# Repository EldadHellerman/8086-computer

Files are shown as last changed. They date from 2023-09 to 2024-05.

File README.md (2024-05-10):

# 8086 computer

A single board 8086 based computer with a full keyboard and RGB LCD screen.
The project includes an assembler, and maybe in the future a c compiler.

It's a new version of my 8086 computer (the old one moved to repository "8086_OLD").
This one focuses mainly on PCB design.

Folders in this repository:
 - 8086 board - KiCad project folder. Schematics and PCB design.
 - assembler - Custom 8086 assembler.
 - coprocessor - Software for the coprocessor.
 - companion - Utility to communicate with the coprocessor.

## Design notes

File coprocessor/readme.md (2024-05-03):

# Coprocessor

The coprocessor is used for:
 - Generating a clock for the 8086 - The clock is required to be 33% duty cycle.
 - Generating reset signal for the 8086 - Reset is needed for a minimum clock cycles number.
 - Bridging between USB and the 8086 - It uses UART and shows as a COM port when connected to USB.
 - Reading and writing to memory - Used to upload programs, dump memory, control IO, and so on.
 - Generate interrupts - Reguler interrupts (256 different types) and NMI can be generated.
 - Test signal - Control over 8086 Test signal.
 - OPTIONAL: different peripherals:
    The coprocessor has part of the address space and can be used as different peripherals for the 8086.
    Either via direct memory r/w instructions (if AVR is fast enough), or via shared memory in RAM.
    The peripherals may be:
    - UART - using coprocessor's UART.
    - Timers - using coprocessor's timers.
    - DMA
    - FPU
    - Touch screen - ADC6 and ADC7 are available for reading,
      for driving, READY and TEST are available, and on bus hold, INTA and RCLK are available.
    - SD card - maybe common SPI lines, and use 8086 ???? as SD card CS.

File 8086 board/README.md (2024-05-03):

# 8086 board
This folder is a KiCad project folder.
It includes the 8086 PC schematics and PCB design.

## Board details

### General
- The 8086 itself.
- 128/256kB SRAM + 1024kB flash with bank select switch (only 512kB are addressable at a time, so flash is divided into two banks, meaning two complete programs can be stored at once, and selected from using the switch before boot).
- Logic for address latching (including OR gate with bus ALE).
- Expansion port allowing access to 8086 bus.
This may be used for future developments - perhapse an FPGA graphics card with HDMI output.
- LED indicators for: latched adderss, memory access (SRAM 1, SRAM 2, Flash is A19, MCU, and LCD).
- Reset button.
- USB-C port for power and communication with coprocessor.

### IO
- 320*240 or 480*320 RGB 40 pin LCD.
- 32 Push Buttons.  
They form a keyboard, with 'a'-'z', space, enter, backspace, CTRL, ALT, SHIFT.
- Logic to latch data from buttons.

### Co-Processor
- Mircocontroller used to control the 8086 (generating clock and reset signals), programming the memory and generating interrupts.
- Clock source: if I dont want to generate 33% duty cycle, than maybe a lower frequency 50% duty cycle instead.
  (make 66% of 8MHz the 50% of frequency - which is 6MHz).
- Maybe also act as peripherals (with or without interrupts): timers, UART, mouse (input from touch screen), SD card interface, etc...
- USB to UART convertor (CH340C).
- USB-C port for power and to connect to computer.
- UART connector (4p header pins or JST-XH).

## Address Space

### Segments and physical address

The 8086 uses 20-bit addressing (for 1MB total).  
The physical address is calculated from a 16-bit segment register and a 16-bit address register:

```
physical address = (segment << 4) + offset
```

For convenience, I will think of each segment as being only the 4 highest order bits (0x?000), and the memory as being comprised of 16 segments, each 64kB in size.
    
For in / out instructions, only 16-bits addressing is allowed (first segment only).

The 8086 boots to address 0xFFFF0, so there must be some memory there. That's why the flash is at the top of the memory map.  
Interrupt vector table is at 0x000 - 0x100. That's why the SRAM is at the bottom of the memory map.

<details>
<summary>Tables of memory and IO maps:</summary>

### Memory map

| Addresses | Segments  | Size  | Description |
| --- | --- | ----- | --- |
| 0x0_0000 - 0x2_0000 | 0 - 1 | 128kB | SRAM |
| 0x2_0000 - 0x4_0000 | 2 - 3 | 128kB | optional additional SRAM |
| 0x4_0000 - 0x6_0000 | 4 - 5 | 128kB | MMIO - Microcontroller |
| 0x6_0000 - 0x7_0000 | 6 | 64 kB | MMIO - RGB LCD - DATA |
| 0x7_8000 - 0x8_0000 | 7 | 64 kB | MMIO - RGB LCD  - COMMAND |
| 0x8_0000 - 0xF_FFFF | 8 - 15 | 512kB | Flash |

### IO map

IO ports are 16-bit wide.

| Number | Address | Read description | Write description |
| --- | --- | --- | --- |
| 0 | 0x0000 | 16 Push buttons. | FREE |
| 1 | 0x0002 | 16 Push buttons. | FREE |
| 2 - 7 | 0x0004 - 0x000E | FREE | FREE |

</details>

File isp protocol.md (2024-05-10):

# ISP protocol
Version 2.1  

The ISP protocol is used for communicating with the coprocessor.
This communication happens over serial, using the coprocessor UART to USB adapter.  

General structure:
- The protocol consists of packets.
- The protocol is little endian (i.e 0x1234 is sent as 0x34 and then 0x12). This matches with UART being LSB first.
- Each packet is either a command or a response. Each command is answered with a response.
- Only the computer may send commands, Only the coprocessor may send responses.
- Registers are used to control different functions, and set different settings of the coprocessor.
- Registers are identified by a 1-byte number, and are 4-bytes wide (although using only parts of the bits is possible).

Packets have the following fields (at that order):
| field name | size (bytes)  |
| --- | --- |
| preamble | 2 |
| packet id | 1 |
| data length | 2 |
| data | 0 - 65,535 |

For preamble, the value 0xAA55 is used.

## Packets:
| packet id | name | type | description | data length | data (length in bytes) |
| --- | --- | --- | --- | --- | --- |
| 0x00 | READ_REG | command  | read from a register | 1 | register number (1) |
| 0x01 | WRITE_REG | command  | write to a register | 5 | register number (1), value (4) |
| 0x02 | READ_BUS | command  | read from the bus | 6 | address (4), length (2) |
| 0x03 | WRITE_BUS | command  | write to the bus | variable | address (4), data (variable) |
| 0x04 | WRITE_FLASH | command  | write to / program flash | variable | address (4), data (variable) |
| 0x10 | SUCCESS | response | successful operation | 0 | none |
| | | | successful READ_REGISTER | 4 | value of register (4) |
| | | | successful READ_BUS | variable | data (variable) |
| 0x11 | FAILURE | response | failure | 0 | none |

## Registers:
| number | name | value on read | value on read description | value on write | value on write description |
| --- | --- | --- | --- | --- | --- |
| 0x00 | STATUS | status | status. indicates error types TODO | status | |
| 0x01 | DEVICE_ID | 0xXXXXXXXX | unique device id | | |
| 0x02 | FIRMWARE_VERSION | 0xXXXXXXXX | firmware version | | |
| 0x03 | PROTOCOL_VERSION | 0xXXXXXXXX | protocol version | | |
| 0x04 | CLOCK_SPEED | TODO | generated clock speed | TODO | same |
| 0x05 | UART_SPEED | TODO | communication uart speed | TODO | same |
| 0x06 | RESET_TIME | TODO | TODO | TODO | same |
| 0x07 | TIMEOUT | TODO | TODO | TODO | same |
| 0x08 | GPIO_TEST | 0 - 1 | input level of test pin | 0 - 1 | output level of test pin |
| 0x10 | RESET | | | 1 | Resets the 8086 |
| | | | | 2 | Resets 8086 and holds bus |
| 0x11 | BUS_HOLD | 0 - 1 | Bus on hold indicator | 0 - 1 | Release or hold bus |
| 0x12 | INTERRUPT | | | 0 - 255 | Generates corresponding interrupts |
| | | | | 256 | Generates NMI |

### Status register:
| bit index | description |
| --- | --- |
| 0 | INVALID_PACKET_ID |
| 1 | INVALID_REGISTER |
| 2 | INVALID_DATA_LENGTH |

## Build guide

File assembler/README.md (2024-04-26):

# Assembler

## Assembly syntax and directives

Comments:
```
// this is a one line comment
/* this is
a multiline comment */
```

labels:  
```
/*
All labels start with '$'.
'$' is the location at the start of current line.
*/

$jump: //defining label
    mov ax, $jump //using label
    mov ax, [$jump] //using label
    jmp $continue + 1 // label math, skip NOP
$continue:
    NOP
    JMP $ // infinite loop
```

Line endings:
```
/*
';' is used to seperate commands on the same line.
'\n' or '\r\n' are used to move to next line.
*/
mov ax, 5; mov bx, 6  ;mov cx,7  // Valid. 3 commands in one line.
```

Assembler directives:
All assembler directives start with a dot.
```
.incbin "file.bin"
.section .text
.extern main
```

Constants:
```
// constants prefixes are case insensitive

// integers (underscore seperators are allowed):
.db -24, +35_000                // decimal
.db 0x12_34                     // hex
.db 0o45                        // octal
.db 0b0110_0011                 // binary
.db 'a'                         // ascii
.dd 2.0, -2f, 1.23, +4.35e-2    // float

// String constants:
"str" // This is considered the same as 's', 't', 'r', '\0'.
```

General:
```
mov DST, SRC // DST is on the left, SRC is on the right.

mov byte [0x3456], 0x20
mov AL, byte [0x3456]
mov AL, [0x3456] // Implicit byte. Optional warning.

mov [0x3456], 0x20 // Unknowen size. Error.
inc [0x3456] // Unknowen size. Error.

mov ax, [ES : 0x04] // Segment override is inside the square brackets.
```

## Preprocessor Directives

```
#include "file"
#ifndef GUARD
#define GUARD
#endif

#define const 5

#define macro1(x)   mov ax, 5
#define macro2(a,b) (bp + si + a*8 + b)

#macro macro3
    mov ax, 0
    ret
#endmacro

#if 4 < 5
mov ax, 5
#endif
```

Comments:
```
// this is a one line comment
/* this is
a multiline comment */
```

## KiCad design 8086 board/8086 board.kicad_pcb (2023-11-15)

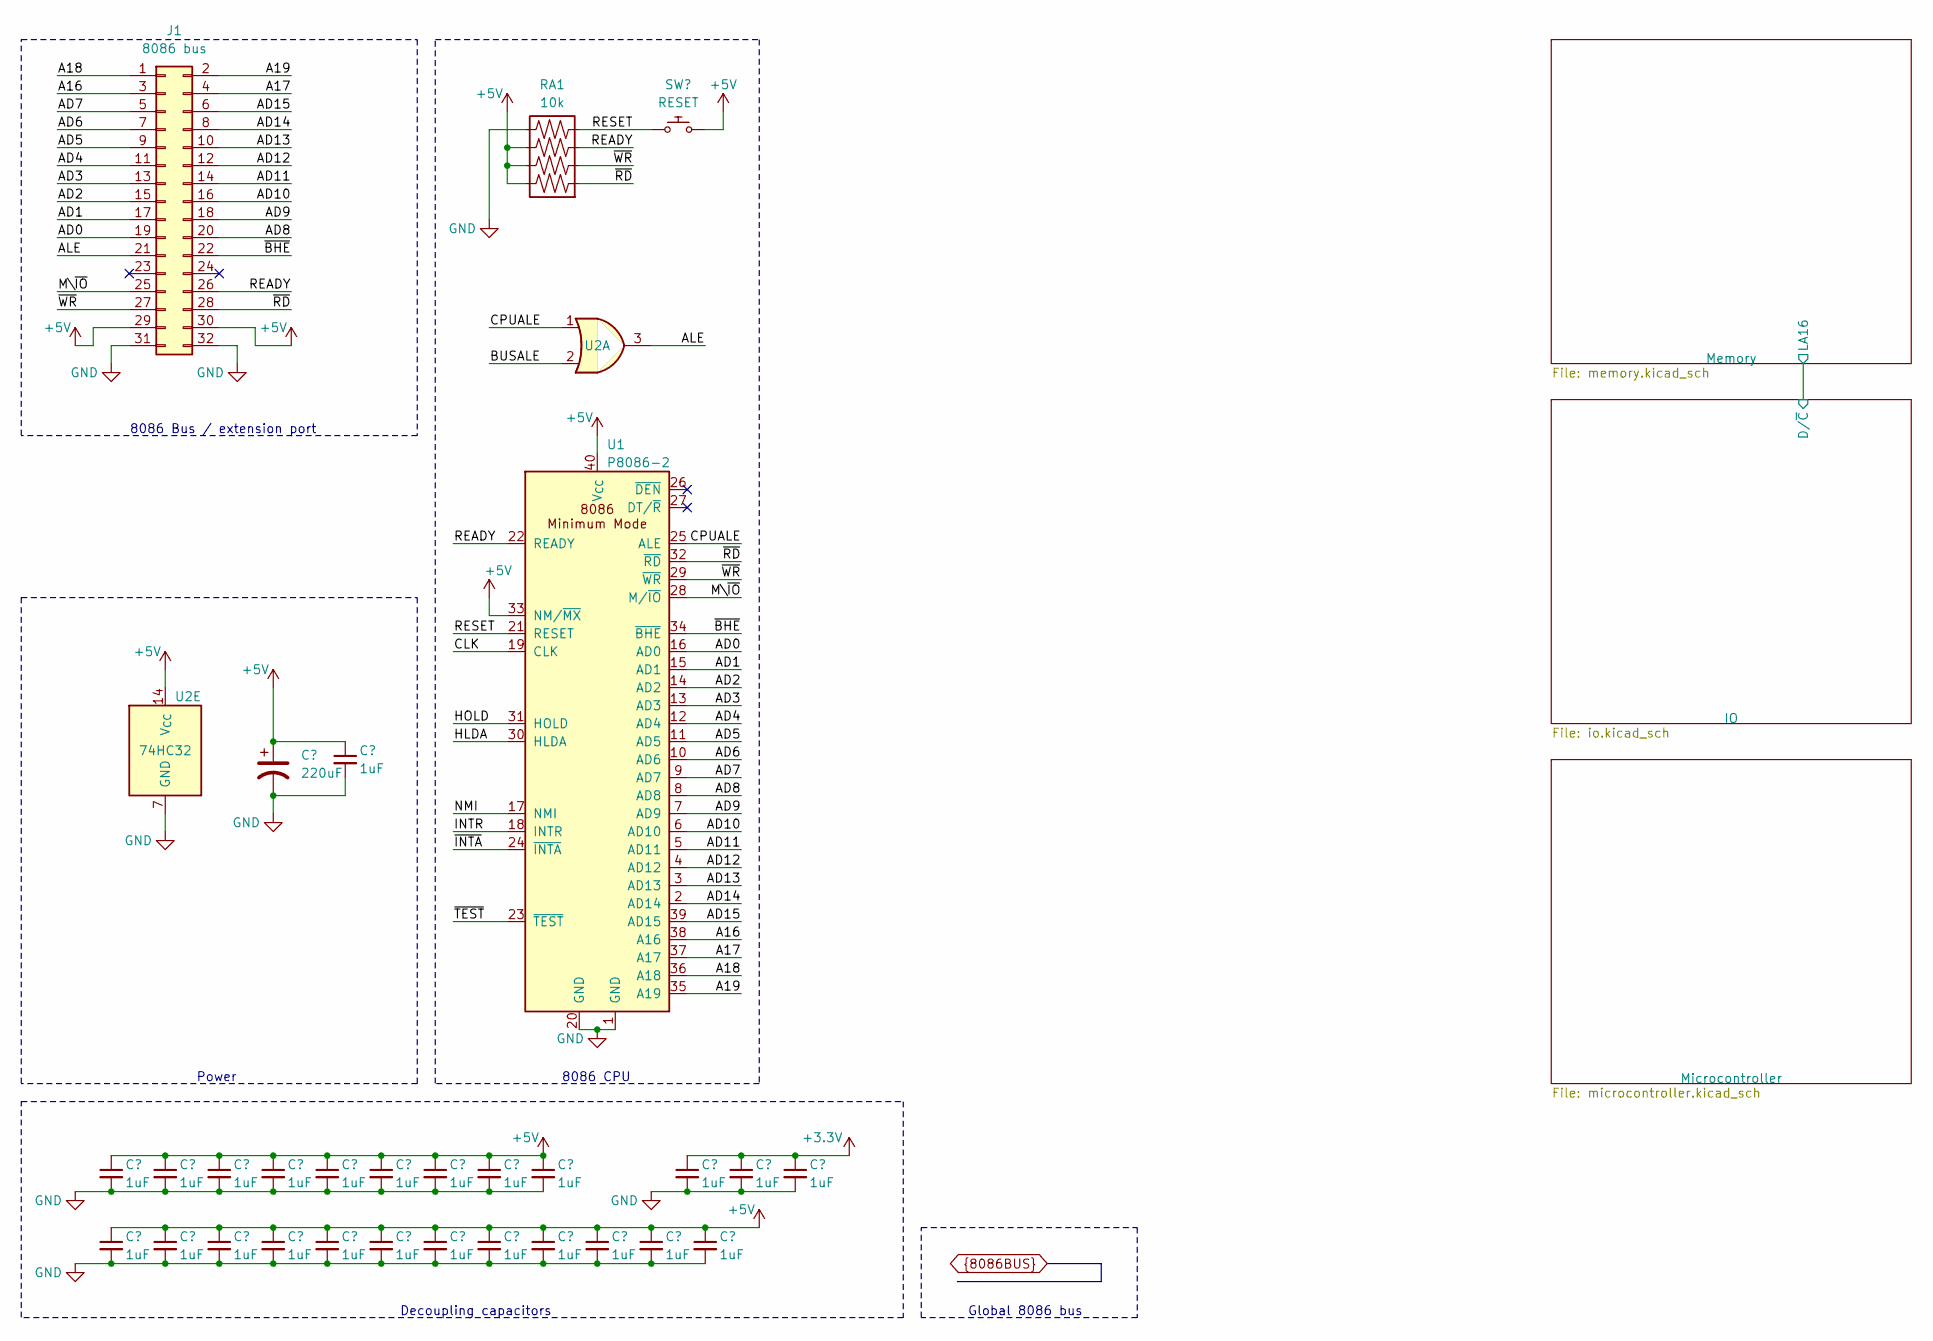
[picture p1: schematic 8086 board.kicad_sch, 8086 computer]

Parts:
C3: 220uF; CP_EIA-7343-43_Kemet-X_Pad2.25x2.55mm_HandSolder
C8, C9, C10, C11, C12, C13, C14, C15, C16, C17, C18, C19, C20, C21, C22, C23, C24, C25, C26, C27, C28, C29, C30, C31, C32: 1uF; C_0603_1608Metric_Pad1.08x0.95mm_HandSolder
J1: 8086 bus; PinHeader_2x16_P2.54mm_Vertical
RA1: 10k; R_Array_Concave_4x0603
SW33: RESET; SW_Push_6x6x5mm
U1: P8086-2; DIP-40_W15.24mm
U2: 74HC32; TSSOP-14_4.4x5mm_P0.65mm

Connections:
+3.3V: C17.1, C18.1, C19.1; also elsewhere on the board
+5V: C3.1, C8.1, C9.1, C10.1, C11.1, C12.1, C13.1, C14.1, C15.1, C16.1, C20.1, C21.1, C22.1, C23.1, C24.1, C25.1, C26.1, C27.1, C28.1, C29.1, C30.1, C31.1, C32.1, J1.29, J1.30, RA1.6, RA1.7, RA1.8, SW33.1, U1.33 (NM/~MX), U1.40 (V_{CC}), U2.14 (V_{CC}); also elsewhere on the board
/CPUALE: U1.25 (ALE), U2.1
A16: J1.3, U1.38 (A16); also elsewhere on the board
A17: J1.4, U1.37 (A17); also elsewhere on the board
A18: J1.1, U1.36 (A18); also elsewhere on the board
A19: J1.2, U1.35 (A19); also elsewhere on the board
AD0: J1.19, U1.16 (AD0); also elsewhere on the board
AD1: J1.17, U1.15 (AD1); also elsewhere on the board
AD2: J1.15, U1.14 (AD2); also elsewhere on the board
AD3: J1.13, U1.13 (AD3); also elsewhere on the board
AD4: J1.11, U1.12 (AD4); also elsewhere on the board
AD5: J1.9, U1.11 (AD5); also elsewhere on the board
AD6: J1.7, U1.10 (AD6); also elsewhere on the board
AD7: J1.5, U1.9 (AD7); also elsewhere on the board
AD8: J1.20, U1.8 (AD8); also elsewhere on the board
AD9: J1.18, U1.7 (AD9); also elsewhere on the board
AD10: J1.16, U1.6 (AD10); also elsewhere on the board
AD11: J1.14, U1.5 (AD11); also elsewhere on the board
AD12: J1.12, U1.4 (AD12); also elsewhere on the board
AD13: J1.10, U1.3 (AD13); also elsewhere on the board
AD14: J1.8, U1.2 (AD14); also elsewhere on the board
AD15: J1.6, U1.39 (AD15); also elsewhere on the board
ALE: J1.21, U2.3; also elsewhere on the board
BUSALE: U2.2; also elsewhere on the board
CLK: U1.19 (CLK); also elsewhere on the board
GND: C3.2, C8.2, C9.2, C10.2, C11.2, C12.2, C13.2, C14.2, C15.2, C16.2, C17.2, C18.2, C19.2, C20.2, C21.2, C22.2, C23.2, C24.2, C25.2, C26.2, C27.2, C28.2, C29.2, C30.2, C31.2, C32.2, J1.31, J1.32, RA1.5, U1.1 (GND), U1.20 (GND), U2.7 (GND); also elsewhere on the board
HLDA: U1.30 (HLDA); also elsewhere on the board
HOLD: U1.31 (HOLD); also elsewhere on the board
INTR: U1.18 (INTR); also elsewhere on the board
M\~IO: J1.25, U1.28 (M/~IO); also elsewhere on the board
NMI: U1.17 (NMI); also elsewhere on the board
READY: J1.26, RA1.3, U1.22 (READY); also elsewhere on the board
RESET: RA1.4, SW33.2, U1.21 (RESET); also elsewhere on the board
~BHE: J1.22, U1.34 (~BHE); also elsewhere on the board
~INTA: U1.24 (~INTA); also elsewhere on the board
~RD: J1.28, RA1.1, U1.32 (~RD); also elsewhere on the board
~TEST: U1.23 (~TEST); also elsewhere on the board
~WR: J1.27, RA1.2, U1.29 (~WR); also elsewhere on the board

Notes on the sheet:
Power
8086 Bus / extension port
Decoupling capacitors
Global 8086 bus
8086 CPU

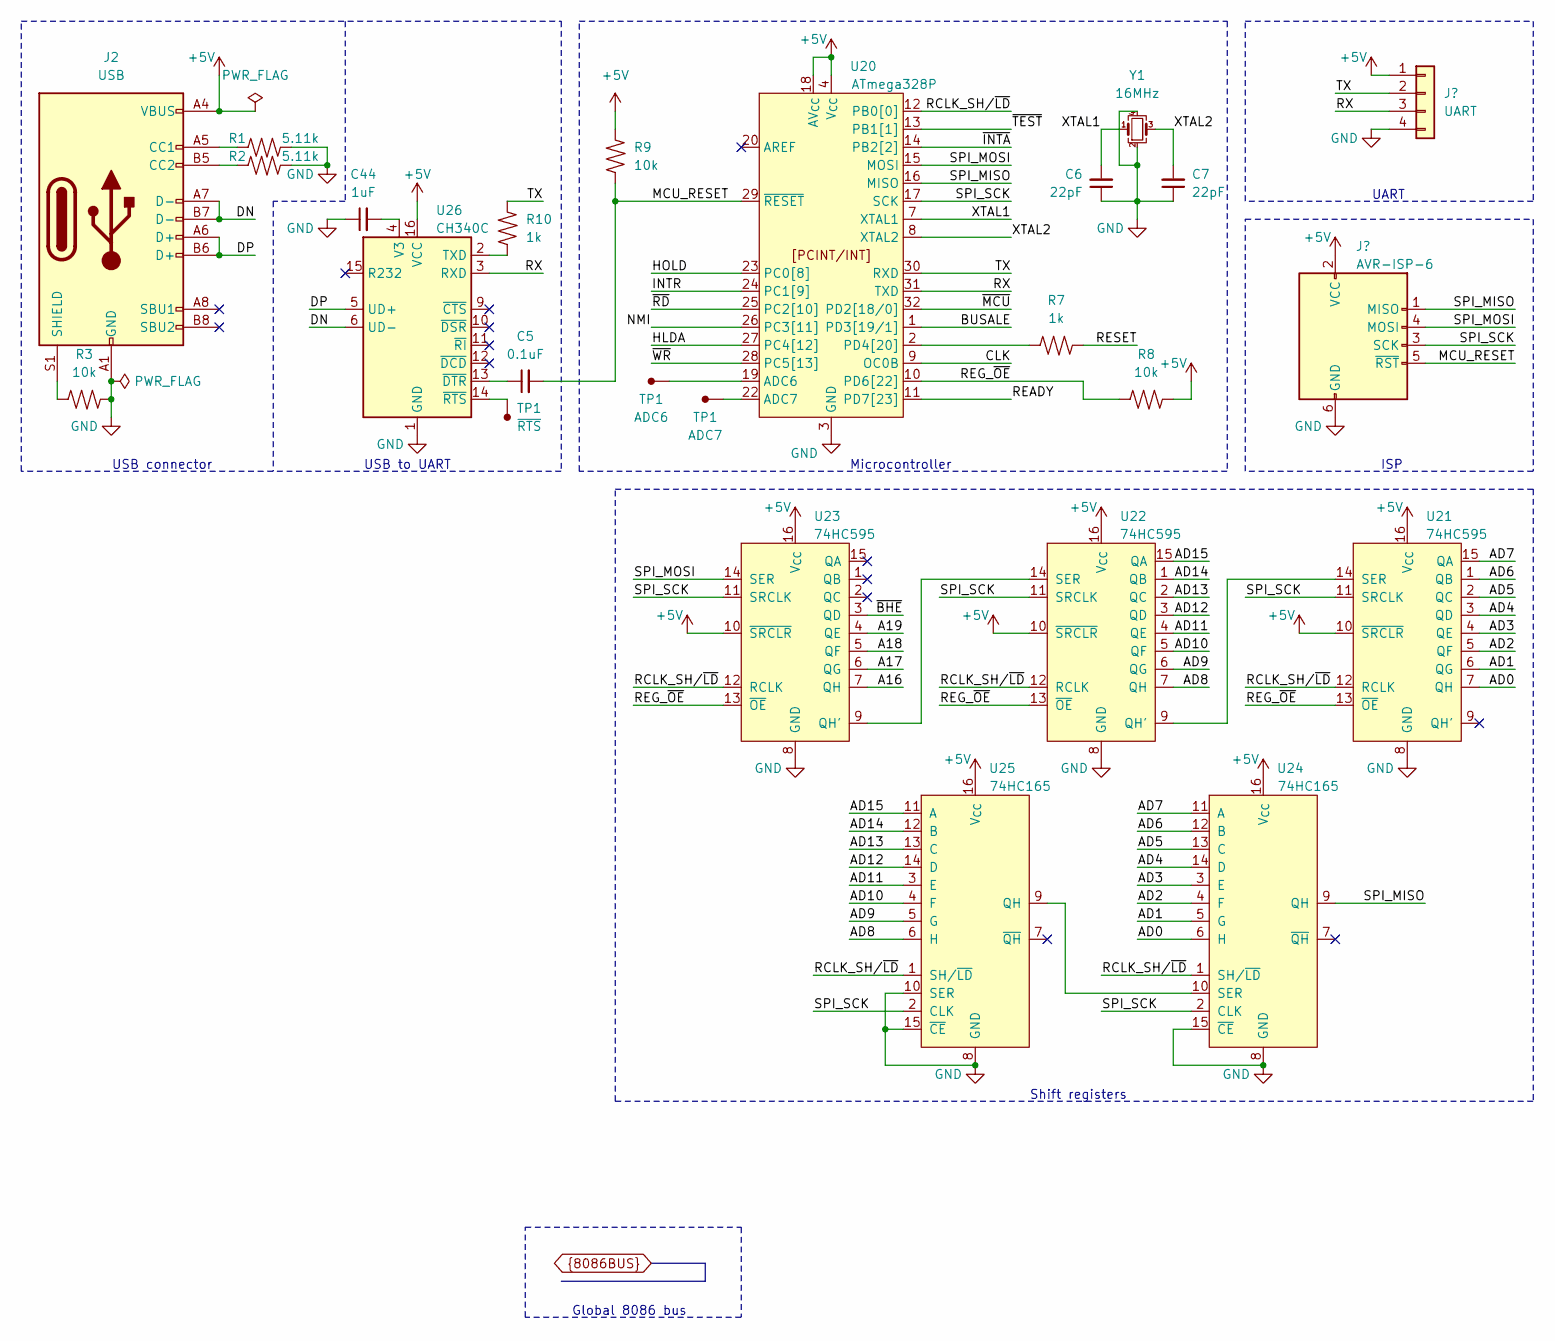
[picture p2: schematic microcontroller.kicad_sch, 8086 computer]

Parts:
C5: 0.1uF; C_0603_1608Metric_Pad1.08x0.95mm_HandSolder
C6, C7: 22pF; C_0603_1608Metric_Pad1.08x0.95mm_HandSolder
C44: 1uF; C_0603_1608Metric_Pad1.08x0.95mm_HandSolder
J2: USB; USB_C_Receptacle_GCT_USB4105-xx-A_16P_TopMnt_Horizontal
J4: UART; PinHeader_1x04_P2.54mm_Vertical
J5: AVR-ISP-6; PinHeader_2x03_P2.54mm_Vertical
R1, R2: 5.11k; R_0603_1608Metric_Pad0.98x0.95mm_HandSolder
R3, R8, R9: 10k; R_0603_1608Metric_Pad0.98x0.95mm_HandSolder
R7, R10: 1k; R_0603_1608Metric_Pad0.98x0.95mm_HandSolder
TP1: ADC6; TestPoint_Pad_1.5x1.5mm
U20: ATmega328P; TQFP-32_7x7mm_P0.8mm
U21, U22, U23: 74HC595; TSSOP-16_4.4x5mm_P0.65mm
U24, U25: 74HC165; TSSOP-16_4.4x5mm_P0.65mm
U26: CH340C; SOIC-16_3.9x9.9mm_P1.27mm
Y1: 16MHz; Crystal_SMD_3225-4Pin_3.2x2.5mm_HandSoldering

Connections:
+5V: J2.A4 (VBUS), J2.A9 (VBUS), J2.B4 (VBUS), J2.B9 (VBUS), J4.1, J5.2 (VCC), R8.2, R9.2, U20.4 (V_{CC}), U20.6 (V_{CC}), U20.18 (AV_{CC}), U21.10 (~SRCLR), U21.16 (V_{CC}), U22.10 (~SRCLR), U22.16 (V_{CC}), U23.10 (~SRCLR), U23.16 (V_{CC}), U24.16 (V_{CC}), U25.16 (V_{CC}); also elsewhere on the board
/Microcontroller/DN: J2.A7 (D-), J2.B7 (D-); also elsewhere on the board
/Microcontroller/DP: J2.A6 (D+), J2.B6 (D+); also elsewhere on the board
/Microcontroller/MCU_RESET: C5.2, J5.5 (~RST), R9.1, U20.29 (~RESET)
/Microcontroller/RCLK_SH/~LD: U20.12 (PB0[0]), U21.12 (RCLK), U22.12 (RCLK), U23.12 (RCLK), U24.1 (SH/~LD), U25.1 (SH/~LD)
/Microcontroller/REG_~OE: R8.1, U20.10 (PD6[22]), U21.13 (~OE), U22.13 (~OE), U23.13 (~OE)
/Microcontroller/RX: J4.3, U20.31 (TXD); also elsewhere on the board
/Microcontroller/SPI_MISO: J5.1 (MISO), U20.16 (MISO), U24.9 (QH)
/Microcontroller/SPI_MOSI: J5.4 (MOSI), U20.15 (MOSI), U23.14 (SER)
/Microcontroller/SPI_SCK: J5.3 (SCK), U20.17 (SCK), U21.11 (SRCLK), U22.11 (SRCLK), U23.11 (SRCLK), U24.2 (CLK), U25.2 (CLK)
/Microcontroller/TX: J4.2, R10.2, U20.30 (RXD)
/Microcontroller/XTAL1: C6.2, U20.7 (XTAL1), Y1.1
/Microcontroller/XTAL2: C7.2, U20.8 (XTAL2), Y1.3
A16: U23.7 (QH); also elsewhere on the board
A17: U23.6 (QG); also elsewhere on the board
A18: U23.5 (QF); also elsewhere on the board
A19: U23.4 (QE); also elsewhere on the board
AD0: U21.7 (QH), U24.6 (H); also elsewhere on the board
AD1: U21.6 (QG), U24.5 (G); also elsewhere on the board
AD2: U21.5 (QF), U24.4 (F); also elsewhere on the board
AD3: U21.4 (QE), U24.3 (E); also elsewhere on the board
AD4: U21.3 (QD), U24.14 (D); also elsewhere on the board
AD5: U21.2 (QC), U24.13 (C); also elsewhere on the board
AD6: U21.1 (QB), U24.12 (B); also elsewhere on the board
AD7: U21.15 (QA), U24.11 (A); also elsewhere on the board
AD8: U22.7 (QH), U25.6 (H); also elsewhere on the board
AD9: U22.6 (QG), U25.5 (G); also elsewhere on the board
AD10: U22.5 (QF), U25.4 (F); also elsewhere on the board
AD11: U22.4 (QE), U25.3 (E); also elsewhere on the board
AD12: U22.3 (QD), U25.14 (D); also elsewhere on the board
AD13: U22.2 (QC), U25.13 (C); also elsewhere on the board
AD14: U22.1 (QB), U25.12 (B); also elsewhere on the board
AD15: U22.15 (QA), U25.11 (A); also elsewhere on the board
BUSALE: U20.1 (PD3[19/1]); also elsewhere on the board
CLK: U20.9 (OC0B); also elsewhere on the board
GND: C6.1, C7.1, J2.A1 (GND), J2.A12 (GND), J2.B1 (GND), J2.B12 (GND), J4.4, J5.6 (GND), R1.2, R2.2, R3.2, U20.3 (GND), U20.5 (GND), U20.21 (GND), U21.8 (GND), U22.8 (GND), U23.8 (GND), U24.8 (GND), U24.15 (~CE), U25.8 (GND), U25.10 (SER), U25.15 (~CE), Y1.2, Y1.4; also elsewhere on the board
HLDA: U20.27 (PC4[12]); also elsewhere on the board
HOLD: U20.23 (PC0[8]); also elsewhere on the board
INTR: U20.24 (PC1[9]); also elsewhere on the board
NMI: U20.26 (PC3[11]); also elsewhere on the board
unnamed: J2.A5 (CC1), R1.1
unnamed: J2.B5 (CC2), R2.1
unnamed: J2.S1 (SHIELD), R3.1
unnamed 155: R10.1; also elsewhere on the board
unnamed 157: C5.1; also elsewhere on the board
unnamed: R7.1, U20.2 (PD4[20])
unnamed: U21.14 (SER), U22.9 (QH')
unnamed: U22.14 (SER), U23.9 (QH')
unnamed: U24.10 (SER), U25.9 (QH)
READY: U20.11 (PD7[23]); also elsewhere on the board
RESET: R7.2; also elsewhere on the board
~BHE: U23.3 (QD); also elsewhere on the board
~INTA: U20.14 (PB2[2]); also elsewhere on the board
~MCU: U20.32 (PD2[18/0]); also elsewhere on the board
~RD: U20.25 (PC2[10]); also elsewhere on the board
~TEST: U20.13 (PB1[1]); also elsewhere on the board
~WR: U20.28 (PC5[13]); also elsewhere on the board

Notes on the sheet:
UART
ISP
Microcontroller
USB to UART
USB connector
Global 8086 bus
Shift registers

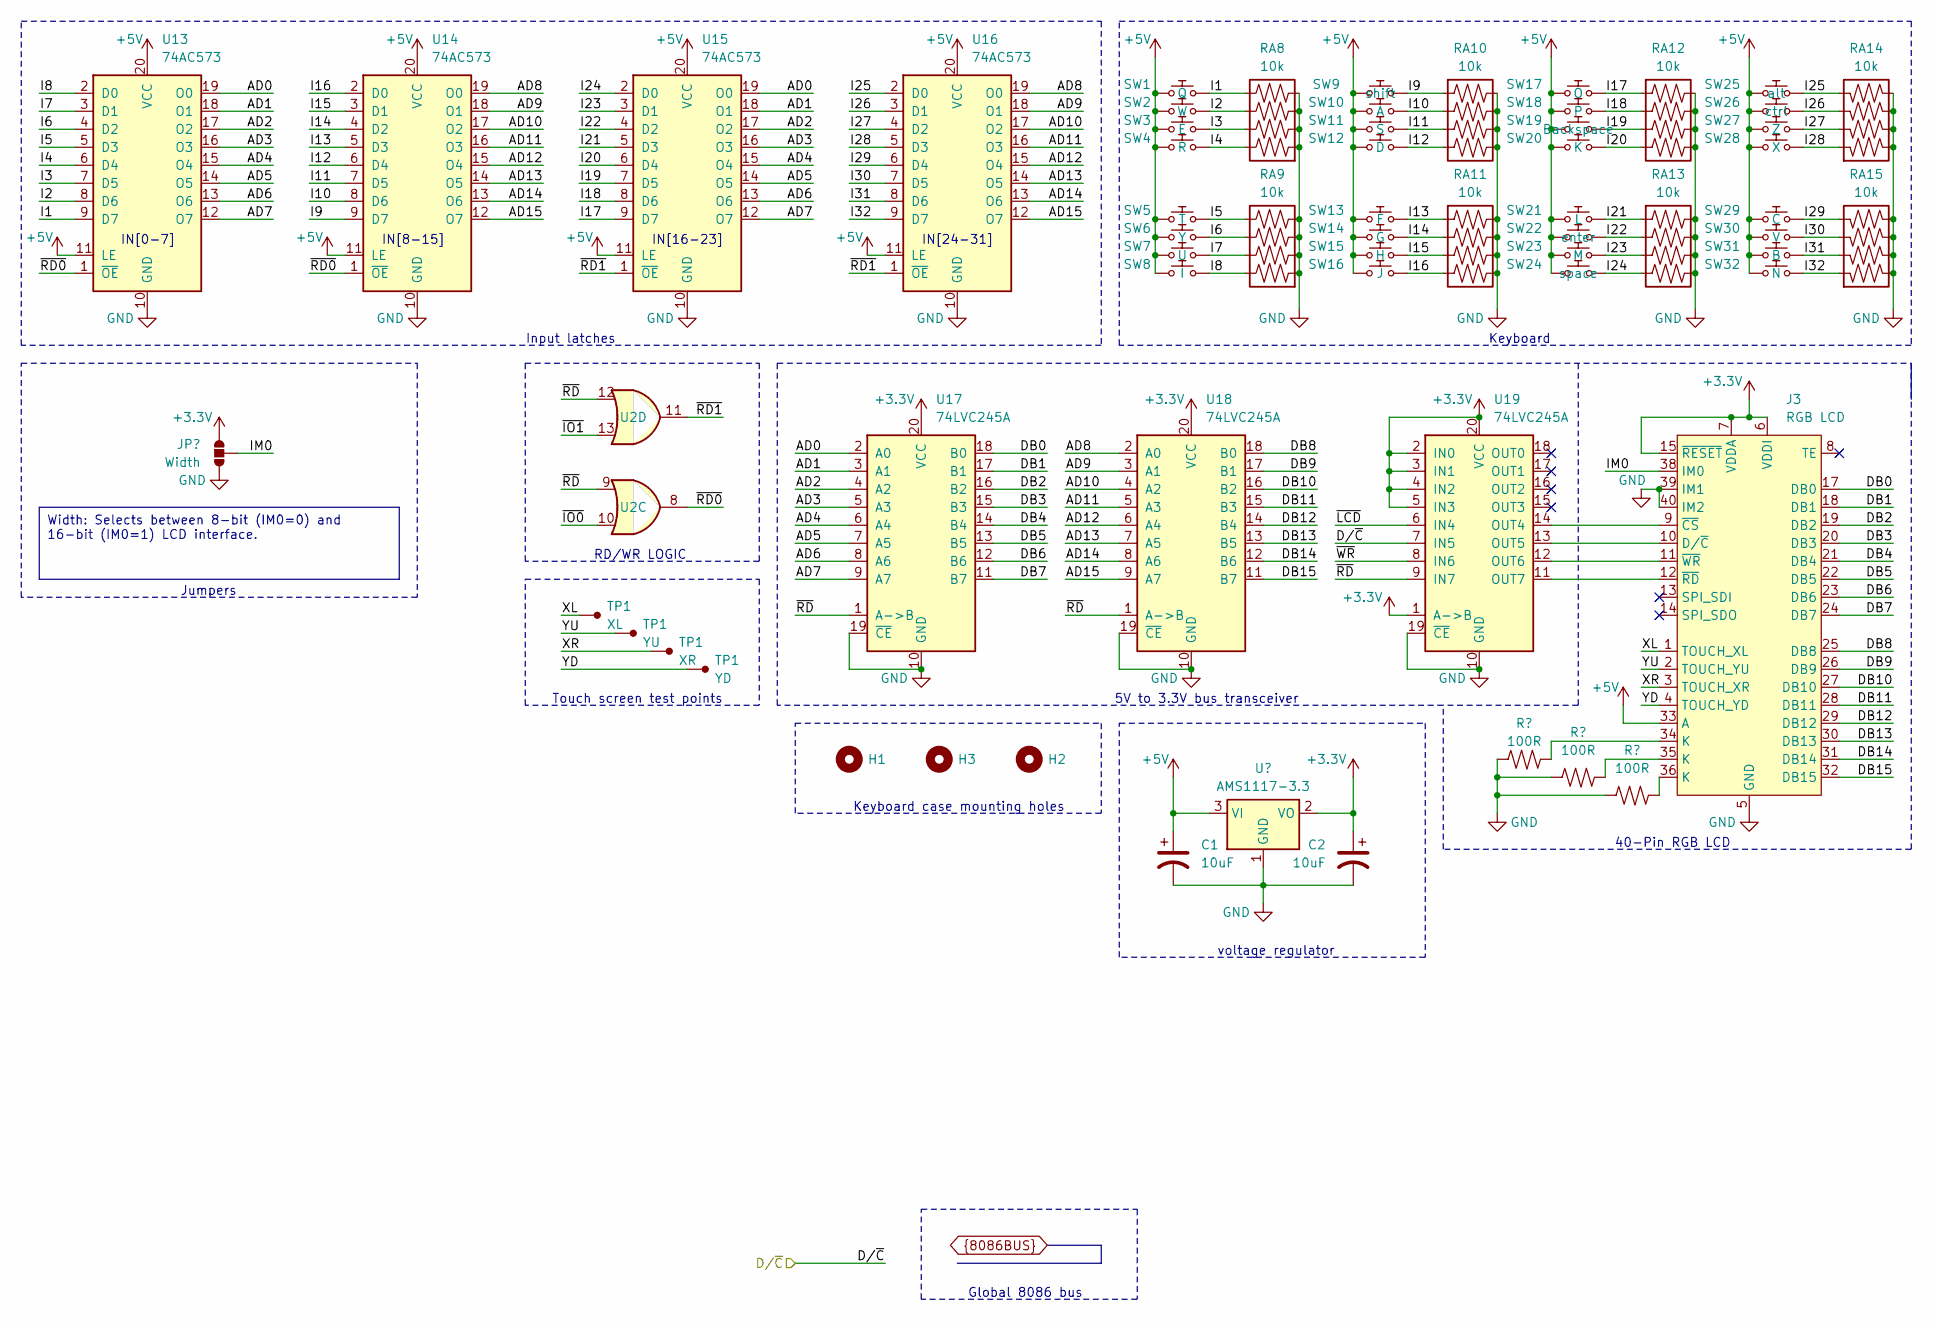
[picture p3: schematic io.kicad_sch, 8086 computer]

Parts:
C1, C2: 10uF; C_0603_1608Metric_Pad1.08x0.95mm_HandSolder
H1, H2, H3: MountingHole_3.2mm_M3_DIN965
J3: RGB LCD; FPC_40
JP1: Width; SolderJumper-3_P1.3mm_Bridged12_RoundedPad1.0x1.5mm
R4, R5, R6: 100R; R_0603_1608Metric_Pad0.98x0.95mm_HandSolder
RA8, RA9, RA10, RA11, RA12, RA13, RA14, RA15: 10k; R_Array_Concave_4x0603
SW1: Q; SW_Push_6x6x5mm
SW2: W; SW_Push_6x6x5mm
SW3: E; SW_Push_6x6x5mm
SW4: R; SW_Push_6x6x5mm
SW5: T; SW_Push_6x6x5mm
SW6: Y; SW_Push_6x6x5mm
SW7: U; SW_Push_6x6x5mm
SW8: I; SW_Push_6x6x5mm
SW9: shift; SW_Push_6x6x5mm
SW10: A; SW_Push_6x6x5mm
SW11: S; SW_Push_6x6x5mm
SW12: D; SW_Push_6x6x5mm
SW13: F; SW_Push_6x6x5mm
SW14: G; SW_Push_6x6x5mm
SW15: H; SW_Push_6x6x5mm
SW16: J; SW_Push_6x6x5mm
SW17: O; SW_Push_6x6x5mm
SW18: P; SW_Push_6x6x5mm
SW19: Backspace; SW_Push_6x6x5mm
SW20: K; SW_Push_6x6x5mm
SW21: L; SW_Push_6x6x5mm
SW22: enter; SW_Push_6x6x5mm
SW23: M; SW_Push_6x6x5mm
SW24: space; SW_Push_6x6x5mm
SW25: alt; SW_Push_6x6x5mm
SW26: ctrl; SW_Push_6x6x5mm
SW27: Z; SW_Push_6x6x5mm
SW28: X; SW_Push_6x6x5mm
SW29: C; SW_Push_6x6x5mm
SW30: V; SW_Push_6x6x5mm
SW31: B; SW_Push_6x6x5mm
SW32: N; SW_Push_6x6x5mm
TP1: XR; TestPoint_Pad_1.5x1.5mm
U2: 74HC32; TSSOP-14_4.4x5mm_P0.65mm
U3: AMS1117-3.3; SOT-223-3_TabPin2
U13, U14, U15, U16: 74AC573; TSSOP-20_4.4x6.5mm_P0.65mm
U17, U18, U19: 74LVC245A; TSSOP-20_4.4x6.5mm_P0.65mm

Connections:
+3.3V: C2.1, J3.6 (VDDI), J3.7 (VDDA), J3.15 (~RESET), JP1.1, U3.2 (VO), U17.20 (VCC), U18.20 (VCC), U19.1 (A->B), U19.2 (IN0), U19.3 (IN1), U19.4 (IN2), U19.5 (IN3), U19.20 (VCC); also elsewhere on the board
+5V: C1.1, J3.33 (A), SW1.1, SW2.2, SW3.1, SW4.2, SW5.1, SW6.2, SW7.1, SW8.2, SW9.1, SW10.2, SW11.1, SW12.2, SW13.1, SW14.2, SW15.1, SW16.2, SW17.1, SW18.2, SW19.1, SW20.1, SW21.2, SW22.1, SW23.1, SW24.1, SW25.1, SW26.2, SW27.1, SW28.2, SW29.1, SW30.2, SW31.1, SW32.2, U3.3 (VI), U13.11 (LE), U13.20 (VCC), U14.11 (LE), U14.20 (VCC), U15.11 (LE), U15.20 (VCC), U16.11 (LE), U16.20 (VCC); also elsewhere on the board
/IO/DB0: J3.17 (DB0), U17.18 (B0)
/IO/DB1: J3.18 (DB1), U17.17 (B1)
/IO/DB2: J3.19 (DB2), U17.16 (B2)
/IO/DB3: J3.20 (DB3), U17.15 (B3)
/IO/DB4: J3.21 (DB4), U17.14 (B4)
/IO/DB5: J3.22 (DB5), U17.13 (B5)
/IO/DB6: J3.23 (DB6), U17.12 (B6)
/IO/DB7: J3.24 (DB7), U17.11 (B7)
/IO/DB8: J3.25 (DB8), U18.18 (B0)
/IO/DB9: J3.26 (DB9), U18.17 (B1)
/IO/DB10: J3.27 (DB10), U18.16 (B2)
/IO/DB11: J3.28 (DB11), U18.15 (B3)
/IO/DB12: J3.29 (DB12), U18.14 (B4)
/IO/DB13: J3.30 (DB13), U18.13 (B5)
/IO/DB14: J3.31 (DB14), U18.12 (B6)
/IO/DB15: J3.32 (DB15), U18.11 (B7)
/IO/D/~C: U19.7 (IN5); also elsewhere on the board
/IO/I1: RA8.5, SW1.2, U13.9 (D7)
/IO/I2: RA8.6, SW2.1, U13.8 (D6)
/IO/I3: RA8.7, SW3.2, U13.7 (D5)
/IO/I4: RA8.8, SW4.1, U13.6 (D4)
/IO/I5: RA9.5, SW5.2, U13.5 (D3)
/IO/I6: RA9.6, SW6.1, U13.4 (D2)
/IO/I7: RA9.7, SW7.2, U13.3 (D1)
/IO/I8: RA9.8, SW8.1, U13.2 (D0)
/IO/I9: RA10.1, SW9.2, U14.9 (D7)
/IO/I10: RA10.2, SW10.1, U14.8 (D6)
/IO/I11: RA10.3, SW11.2, U14.7 (D5)
/IO/I12: RA10.4, SW12.1, U14.6 (D4)
/IO/I13: RA11.1, SW13.2, U14.5 (D3)
/IO/I14: RA11.2, SW14.1, U14.4 (D2)
/IO/I15: RA11.3, SW15.2, U14.3 (D1)
/IO/I16: RA11.4, SW16.1, U14.2 (D0)
/IO/I17: RA12.1, SW17.2, U15.9 (D7)
/IO/I18: RA12.2, SW18.1, U15.8 (D6)
/IO/I19: RA12.3, SW19.2, U15.7 (D5)
/IO/I20: RA12.4, SW20.2, U15.6 (D4)
/IO/I21: RA13.1, SW21.1, U15.5 (D3)
/IO/I22: RA13.2, SW22.2, U15.4 (D2)
/IO/I23: RA13.3, SW23.2, U15.3 (D1)
/IO/I24: RA13.4, SW24.2, U15.2 (D0)
/IO/I25: RA14.4, SW25.2, U16.2 (D0)
/IO/I26: RA14.3, SW26.1, U16.3 (D1)
/IO/I27: RA14.2, SW27.2, U16.4 (D2)
/IO/I28: RA14.1, SW28.1, U16.5 (D3)
/IO/I29: RA15.4, SW29.2, U16.6 (D4)
/IO/I30: RA15.3, SW30.1, U16.7 (D5)
/IO/I31: RA15.2, SW31.2, U16.8 (D6)
/IO/I32: RA15.1, SW32.1, U16.9 (D7)
/IO/IM0: J3.38 (IM0), JP1.2
/IO/~RD0: U2.8, U13.1 (~OE), U14.1 (~OE)
/IO/~RD1: U2.11, U15.1 (~OE), U16.1 (~OE)
AD0: U13.19 (O0), U15.19 (O0), U17.2 (A0); also elsewhere on the board
AD1: U13.18 (O1), U15.18 (O1), U17.3 (A1); also elsewhere on the board
AD2: U13.17 (O2), U15.17 (O2), U17.4 (A2); also elsewhere on the board
AD3: U13.16 (O3), U15.16 (O3), U17.5 (A3); also elsewhere on the board
AD4: U13.15 (O4), U15.15 (O4), U17.6 (A4); also elsewhere on the board
AD5: U13.14 (O5), U15.14 (O5), U17.7 (A5); also elsewhere on the board
AD6: U13.13 (O6), U15.13 (O6), U17.8 (A6); also elsewhere on the board
AD7: U13.12 (O7), U15.12 (O7), U17.9 (A7); also elsewhere on the board
AD8: U14.19 (O0), U16.19 (O0), U18.2 (A0); also elsewhere on the board
AD9: U14.18 (O1), U16.18 (O1), U18.3 (A1); also elsewhere on the board
AD10: U14.17 (O2), U16.17 (O2), U18.4 (A2); also elsewhere on the board
AD11: U14.16 (O3), U16.16 (O3), U18.5 (A3); also elsewhere on the board
AD12: U14.15 (O4), U16.15 (O4), U18.6 (A4); also elsewhere on the board
AD13: U14.14 (O5), U16.14 (O5), U18.7 (A5); also elsewhere on the board
AD14: U14.13 (O6), U16.13 (O6), U18.8 (A6); also elsewhere on the board
AD15: U14.12 (O7), U16.12 (O7), U18.9 (A7); also elsewhere on the board
GND: C1.2, C2.2, J3.5 (GND), J3.16 (GND), J3.37 (GND), J3.39 (IM1), J3.40 (IM2), JP1.3, R4.1, R5.1, R6.1, RA8.1, RA8.2, RA8.3, RA8.4, RA9.1, RA9.2, RA9.3, RA9.4, RA10.5, RA10.6, RA10.7, RA10.8, RA11.5, RA11.6, RA11.7, RA11.8, RA12.5, RA12.6, RA12.7, RA12.8, RA13.5, RA13.6, RA13.7, RA13.8, RA14.5, RA14.6, RA14.7, RA14.8, RA15.5, RA15.6, RA15.7, RA15.8, U3.1 (GND), U13.10 (GND), U14.10 (GND), U15.10 (GND), U16.10 (GND), U17.10 (GND), U17.19 (~CE), U18.10 (GND), U18.19 (~CE), U19.10 (GND), U19.19 (~CE); also elsewhere on the board
unnamed: J3.10 (D/~C), U19.13 (OUT5)
unnamed: J3.34 (K), R4.2
unnamed: J3.35 (K), R5.2
unnamed: J3.36 (K), R6.2
unnamed: J3.9 (~CS), U19.14 (OUT4)
unnamed: J3.12 (~RD), U19.11 (OUT7)
unnamed: J3.11 (~WR), U19.12 (OUT6)
~IO0: U2.10; also elsewhere on the board
~IO1: U2.13; also elsewhere on the board
~LCD: U19.6 (IN4); also elsewhere on the board
~RD: U2.9, U2.12, U17.1 (A->B), U18.1 (A->B), U19.9 (IN7); also elsewhere on the board
~WR: U19.8 (IN6); also elsewhere on the board

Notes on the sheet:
Width: Selects between 8-bit (IM0=0) and 16-bit (IM0=1) LCD interface.
5V to 3.3V bus transceiver
Global 8086 bus
Touch screen test points
voltage regulator
Keyboard
IN[16-23]
IN[24-31]
Input latches
Keyboard case mounting holes
IN[8-15]
IN[0-7]
RD/WR LOGIC
Jumpers
40-Pin RGB LCD

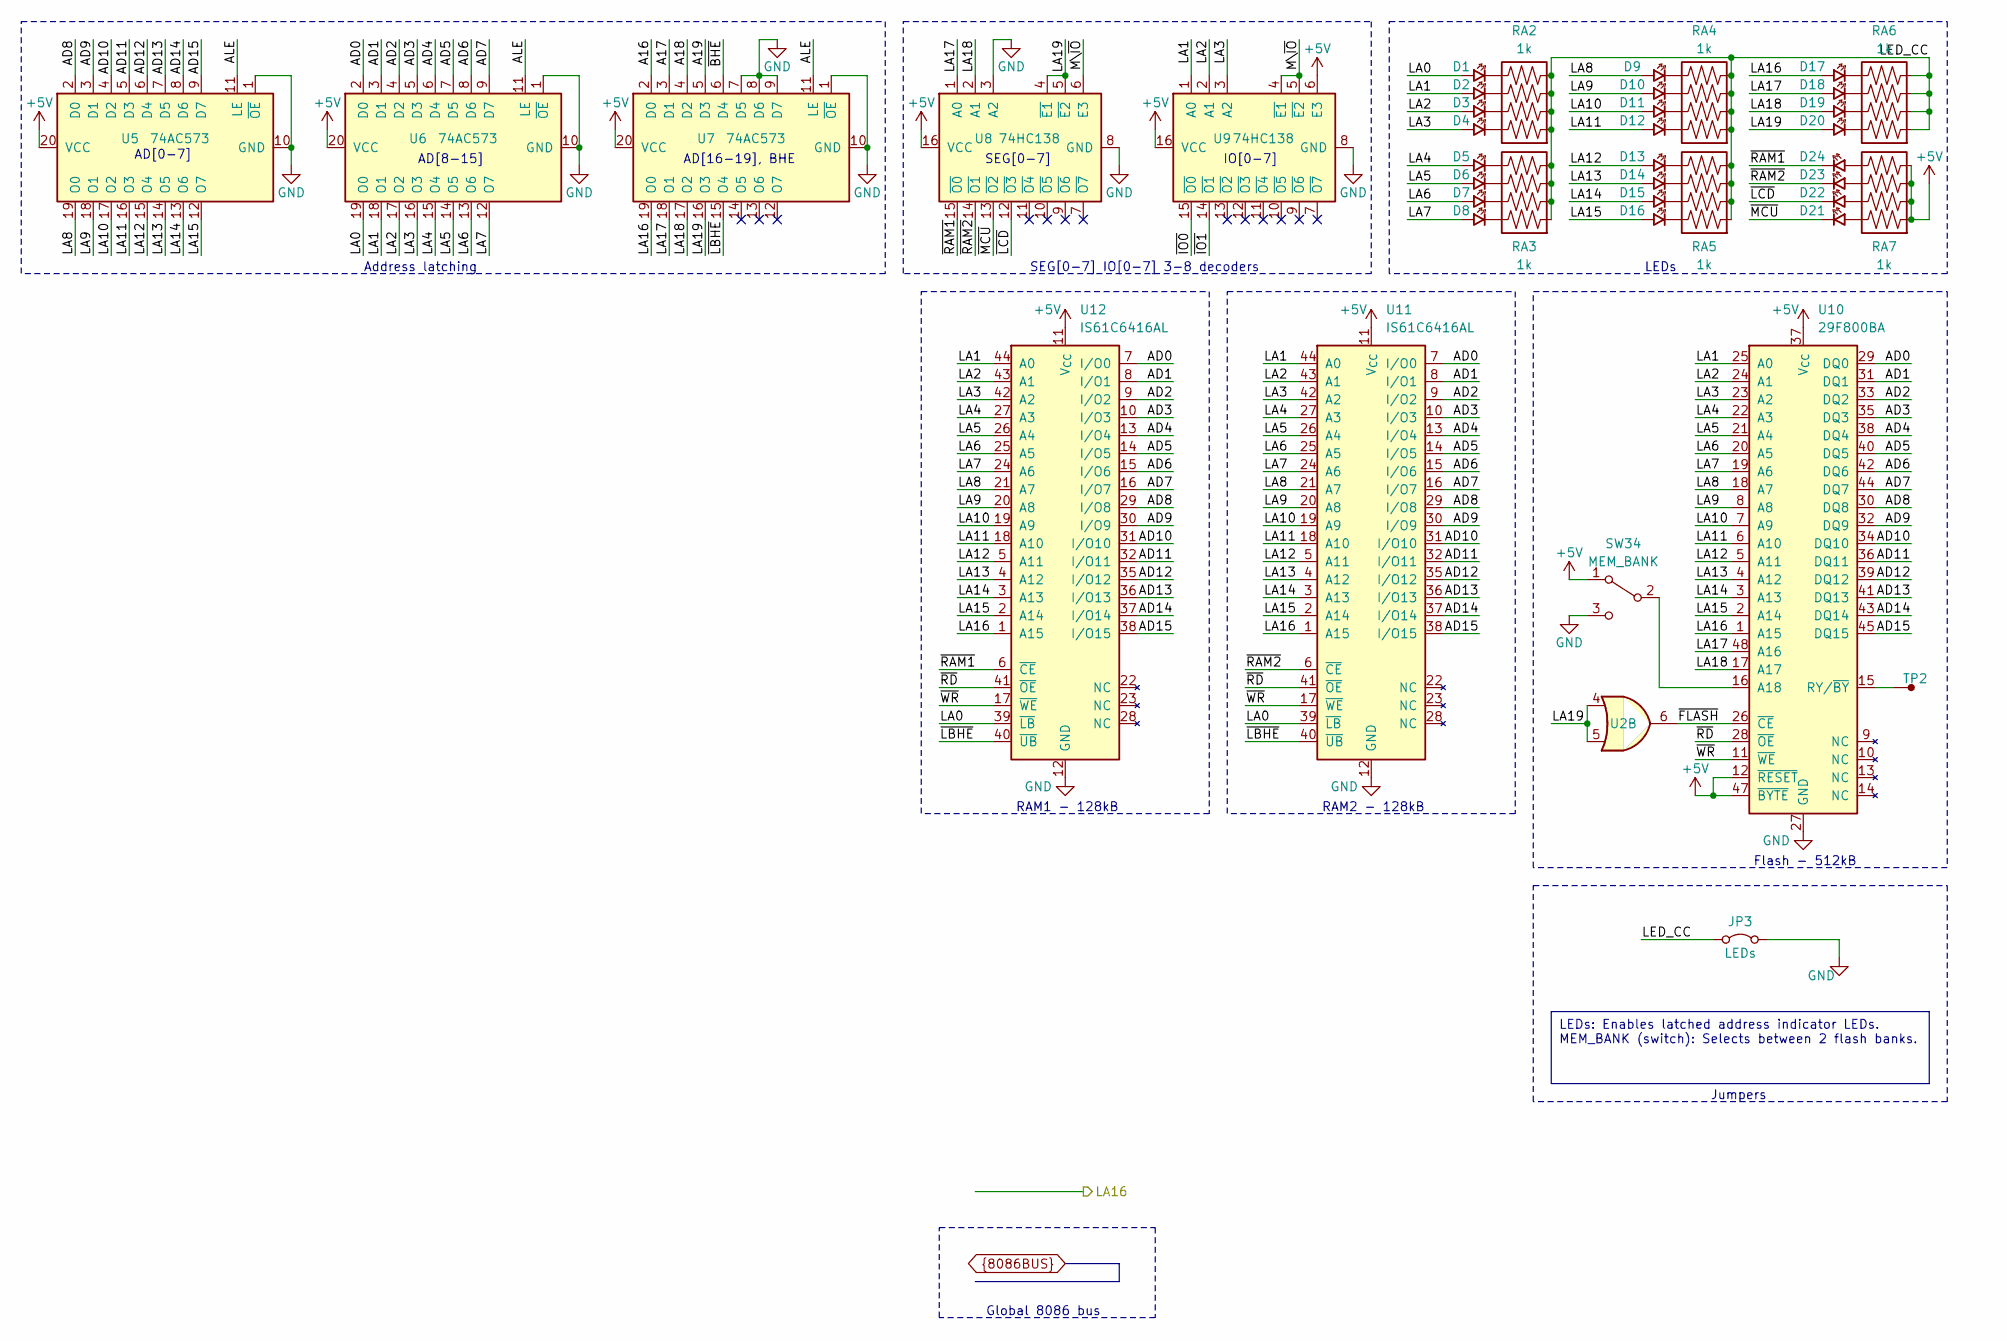
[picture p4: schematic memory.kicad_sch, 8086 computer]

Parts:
D1: A0; LED_0603_1608Metric_Pad1.05x0.95mm_HandSolder
D2: A1; LED_0603_1608Metric_Pad1.05x0.95mm_HandSolder
D3: A2; LED_0603_1608Metric_Pad1.05x0.95mm_HandSolder
D4: A3; LED_0603_1608Metric_Pad1.05x0.95mm_HandSolder
D5: A4; LED_0603_1608Metric_Pad1.05x0.95mm_HandSolder
D6: A5; LED_0603_1608Metric_Pad1.05x0.95mm_HandSolder
D7: A6; LED_0603_1608Metric_Pad1.05x0.95mm_HandSolder
D8: A7; LED_0603_1608Metric_Pad1.05x0.95mm_HandSolder
D9: A8; LED_0603_1608Metric_Pad1.05x0.95mm_HandSolder
D10: A9; LED_0603_1608Metric_Pad1.05x0.95mm_HandSolder
D11: A10; LED_0603_1608Metric_Pad1.05x0.95mm_HandSolder
D12: A11; LED_0603_1608Metric_Pad1.05x0.95mm_HandSolder
D13: A12; LED_0603_1608Metric_Pad1.05x0.95mm_HandSolder
D14: A13; LED_0603_1608Metric_Pad1.05x0.95mm_HandSolder
D15: A14; LED_0603_1608Metric_Pad1.05x0.95mm_HandSolder
D16: A15; LED_0603_1608Metric_Pad1.05x0.95mm_HandSolder
D17: A16; LED_0603_1608Metric_Pad1.05x0.95mm_HandSolder
D18: A17; LED_0603_1608Metric_Pad1.05x0.95mm_HandSolder
D19: A18; LED_0603_1608Metric_Pad1.05x0.95mm_HandSolder
D20: A19; LED_0603_1608Metric_Pad1.05x0.95mm_HandSolder
D21: MCU; LED_0603_1608Metric_Pad1.05x0.95mm_HandSolder
D22: LCD; LED_0603_1608Metric_Pad1.05x0.95mm_HandSolder
D23: RAM2; LED_0603_1608Metric_Pad1.05x0.95mm_HandSolder
D24: RAM1; LED_0603_1608Metric_Pad1.05x0.95mm_HandSolder
JP3: LEDs; SolderJumper-2_P1.3mm_Bridged_RoundedPad1.0x1.5mm
RA2, RA3, RA4, RA5, RA6, RA7: 1k; R_Array_Concave_4x0603
SW34: MEM_BANK; SW_SPDT_PCM12
TP2: TestPoint_Pad_1.0x1.0mm
U2: 74HC32; TSSOP-14_4.4x5mm_P0.65mm
U5, U6, U7: 74AC573; TSSOP-20_4.4x6.5mm_P0.65mm
U8, U9: 74HC138; TSSOP-16_4.4x5mm_P0.65mm
U10: 29F800BA; TSOP-I-48_18.4x12mm_P0.5mm
U11, U12: IS61C6416AL; TSOP-II-44_10.16x18.41mm_P0.8mm

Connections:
+5V: RA7.1, RA7.2, RA7.3, RA7.4, SW34.1 (A), U5.20 (VCC), U6.20 (VCC), U7.20 (VCC), U8.16 (VCC), U9.6 (E3), U9.16 (VCC), U10.12 (~RESET), U10.37 (V_{CC}), U10.47 (~BYTE), U11.11 (V_{CC}), U11.33 (V_{CC}), U12.11 (V_{CC}), U12.33 (V_{CC}); also elsewhere on the board
/IO/D/~C: D17.1 (A), U7.19 (O0), U10.1 (A15), U11.1 (A15), U12.1 (A15); also elsewhere on the board
/Memory/LA0: D1.1 (A), U6.19 (O0), U11.39 (~LB), U12.39 (~LB)
/Memory/LA1: D2.1 (A), U6.18 (O1), U9.1 (A0), U10.25 (A0), U11.44 (A0), U12.44 (A0)
/Memory/LA2: D3.1 (A), U6.17 (O2), U9.2 (A1), U10.24 (A1), U11.43 (A1), U12.43 (A1)
/Memory/LA3: D4.1 (A), U6.16 (O3), U9.3 (A2), U10.23 (A2), U11.42 (A2), U12.42 (A2)
/Memory/LA4: D5.1 (A), U6.15 (O4), U10.22 (A3), U11.27 (A3), U12.27 (A3)
/Memory/LA5: D6.1 (A), U6.14 (O5), U10.21 (A4), U11.26 (A4), U12.26 (A4)
/Memory/LA6: D7.1 (A), U6.13 (O6), U10.20 (A5), U11.25 (A5), U12.25 (A5)
/Memory/LA7: D8.1 (A), U6.12 (O7), U10.19 (A6), U11.24 (A6), U12.24 (A6)
/Memory/LA8: D9.1 (A), U5.19 (O0), U10.18 (A7), U11.21 (A7), U12.21 (A7)
/Memory/LA9: D10.1 (A), U5.18 (O1), U10.8 (A8), U11.20 (A8), U12.20 (A8)
/Memory/LA10: D11.1 (A), U5.17 (O2), U10.7 (A9), U11.19 (A9), U12.19 (A9)
/Memory/LA11: D12.1 (A), U5.16 (O3), U10.6 (A10), U11.18 (A10), U12.18 (A10)
/Memory/LA12: D13.1 (A), U5.15 (O4), U10.5 (A11), U11.5 (A11), U12.5 (A11)
/Memory/LA13: D14.1 (A), U5.14 (O5), U10.4 (A12), U11.4 (A12), U12.4 (A12)
/Memory/LA14: D15.1 (A), U5.13 (O6), U10.3 (A13), U11.3 (A13), U12.3 (A13)
/Memory/LA15: D16.1 (A), U5.12 (O7), U10.2 (A14), U11.2 (A14), U12.2 (A14)
/Memory/LA17: D18.1 (A), U7.18 (O1), U8.1 (A0), U10.48 (A16)
/Memory/LA18: D19.1 (A), U7.17 (O2), U8.2 (A1), U10.17 (A17)
/Memory/LA19: D20.1 (A), U2.4, U2.5, U7.16 (O3), U8.4 (~E1), U8.5 (~E2)
/Memory/LED_CC: JP3.1 (A), RA2.1, RA2.2, RA2.3, RA2.4, RA3.1, RA3.2, RA3.3, RA3.4, RA4.1, RA4.2, RA4.3, RA4.4, RA5.1, RA5.2, RA5.3, RA5.4, RA6.1, RA6.2, RA6.3, RA6.4
/Memory/~FLASH: U2.6, U10.26 (~CE)
/Memory/~LBHE: U7.15 (O4), U11.40 (~UB), U12.40 (~UB)
/Memory/~RAM1: D24.2 (K), U8.15 (~O0), U12.6 (~CE)
/Memory/~RAM2: D23.2 (K), U8.14 (~O1), U11.6 (~CE)
A16: U7.2 (D0); also elsewhere on the board
A17: U7.3 (D1); also elsewhere on the board
A18: U7.4 (D2); also elsewhere on the board
A19: U7.5 (D3); also elsewhere on the board
AD0: U6.2 (D0), U10.29 (DQ0), U11.7 (I/O0), U12.7 (I/O0); also elsewhere on the board
AD1: U6.3 (D1), U10.31 (DQ1), U11.8 (I/O1), U12.8 (I/O1); also elsewhere on the board
AD2: U6.4 (D2), U10.33 (DQ2), U11.9 (I/O2), U12.9 (I/O2); also elsewhere on the board
AD3: U6.5 (D3), U10.35 (DQ3), U11.10 (I/O3), U12.10 (I/O3); also elsewhere on the board
AD4: U6.6 (D4), U10.38 (DQ4), U11.13 (I/O4), U12.13 (I/O4); also elsewhere on the board
AD5: U6.7 (D5), U10.40 (DQ5), U11.14 (I/O5), U12.14 (I/O5); also elsewhere on the board
AD6: U6.8 (D6), U10.42 (DQ6), U11.15 (I/O6), U12.15 (I/O6); also elsewhere on the board
AD7: U6.9 (D7), U10.44 (DQ7), U11.16 (I/O7), U12.16 (I/O7); also elsewhere on the board
AD8: U5.2 (D0), U10.30 (DQ8), U11.29 (I/O8), U12.29 (I/O8); also elsewhere on the board
AD9: U5.3 (D1), U10.32 (DQ9), U11.30 (I/O9), U12.30 (I/O9); also elsewhere on the board
AD10: U5.4 (D2), U10.34 (DQ10), U11.31 (I/O10), U12.31 (I/O10); also elsewhere on the board
AD11: U5.5 (D3), U10.36 (DQ11), U11.32 (I/O11), U12.32 (I/O11); also elsewhere on the board
AD12: U5.6 (D4), U10.39 (DQ12), U11.35 (I/O12), U12.35 (I/O12); also elsewhere on the board
AD13: U5.7 (D5), U10.41 (DQ13), U11.36 (I/O13), U12.36 (I/O13); also elsewhere on the board
AD14: U5.8 (D6), U10.43 (DQ14), U11.37 (I/O14), U12.37 (I/O14); also elsewhere on the board
AD15: U5.9 (D7), U10.45 (DQ15), U11.38 (I/O15), U12.38 (I/O15); also elsewhere on the board
ALE: U5.11 (LE), U6.11 (LE), U7.11 (LE); also elsewhere on the board
GND: JP3.2 (B), SW34.3 (C), U5.1 (~OE), U5.10 (GND), U6.1 (~OE), U6.10 (GND), U7.1 (~OE), U7.7 (D5), U7.8 (D6), U7.9 (D7), U7.10 (GND), U8.3 (A2), U8.8 (GND), U9.8 (GND), U10.27 (GND), U10.46 (GND), U11.12 (GND), U11.34 (GND), U12.12 (GND), U12.34 (GND); also elsewhere on the board
M\~IO: U8.6 (E3), U9.4 (~E1), U9.5 (~E2); also elsewhere on the board
unnamed: D1.2 (K), RA2.5
unnamed: D2.2 (K), RA2.6
unnamed: D3.2 (K), RA2.7
unnamed: D4.2 (K), RA2.8
unnamed: D5.2 (K), RA3.5
unnamed: D6.2 (K), RA3.6
unnamed: D7.2 (K), RA3.7
unnamed: D8.2 (K), RA3.8
unnamed: D9.2 (K), RA4.5
unnamed: D10.2 (K), RA4.6
unnamed: D11.2 (K), RA4.7
unnamed: D12.2 (K), RA4.8
unnamed: D13.2 (K), RA5.5
unnamed: D14.2 (K), RA5.6
unnamed: D15.2 (K), RA5.7
unnamed: D16.2 (K), RA5.8
unnamed: D17.2 (K), RA6.5
unnamed: D18.2 (K), RA6.6
unnamed: D19.2 (K), RA6.7
unnamed: D20.2 (K), RA6.8
unnamed: D21.1 (A), RA7.8
unnamed: D22.1 (A), RA7.7
unnamed: D23.1 (A), RA7.6
unnamed: D24.1 (A), RA7.5
unnamed: SW34.2 (B), U10.16 (A18)
unnamed: TP2.1, U10.15 (RY/~BY)
~BHE: U7.6 (D4); also elsewhere on the board
~IO0: U9.15 (~O0); also elsewhere on the board
~IO1: U9.14 (~O1); also elsewhere on the board
~LCD: D22.2 (K), U8.12 (~O3); also elsewhere on the board
~MCU: D21.2 (K), U8.13 (~O2); also elsewhere on the board
~RD: U10.28 (~OE), U11.41 (~OE), U12.41 (~OE); also elsewhere on the board
~WR: U10.11 (~WE), U11.17 (~WE), U12.17 (~WE); also elsewhere on the board

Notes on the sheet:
LEDs: Enables latched address indicator LEDs. MEM_BANK (switch): Selects between 2 flash banks.
IO[0-7]
AD[16-19], BHE
SEG[0-7] IO[0-7] 3-8 decoders
RAM1 - 128kB
Address latching
AD[0-7]
LEDs
AD[8-15]
SEG[0-7]
Jumpers
RAM2 - 128kB
Flash - 512kB
Global 8086 bus

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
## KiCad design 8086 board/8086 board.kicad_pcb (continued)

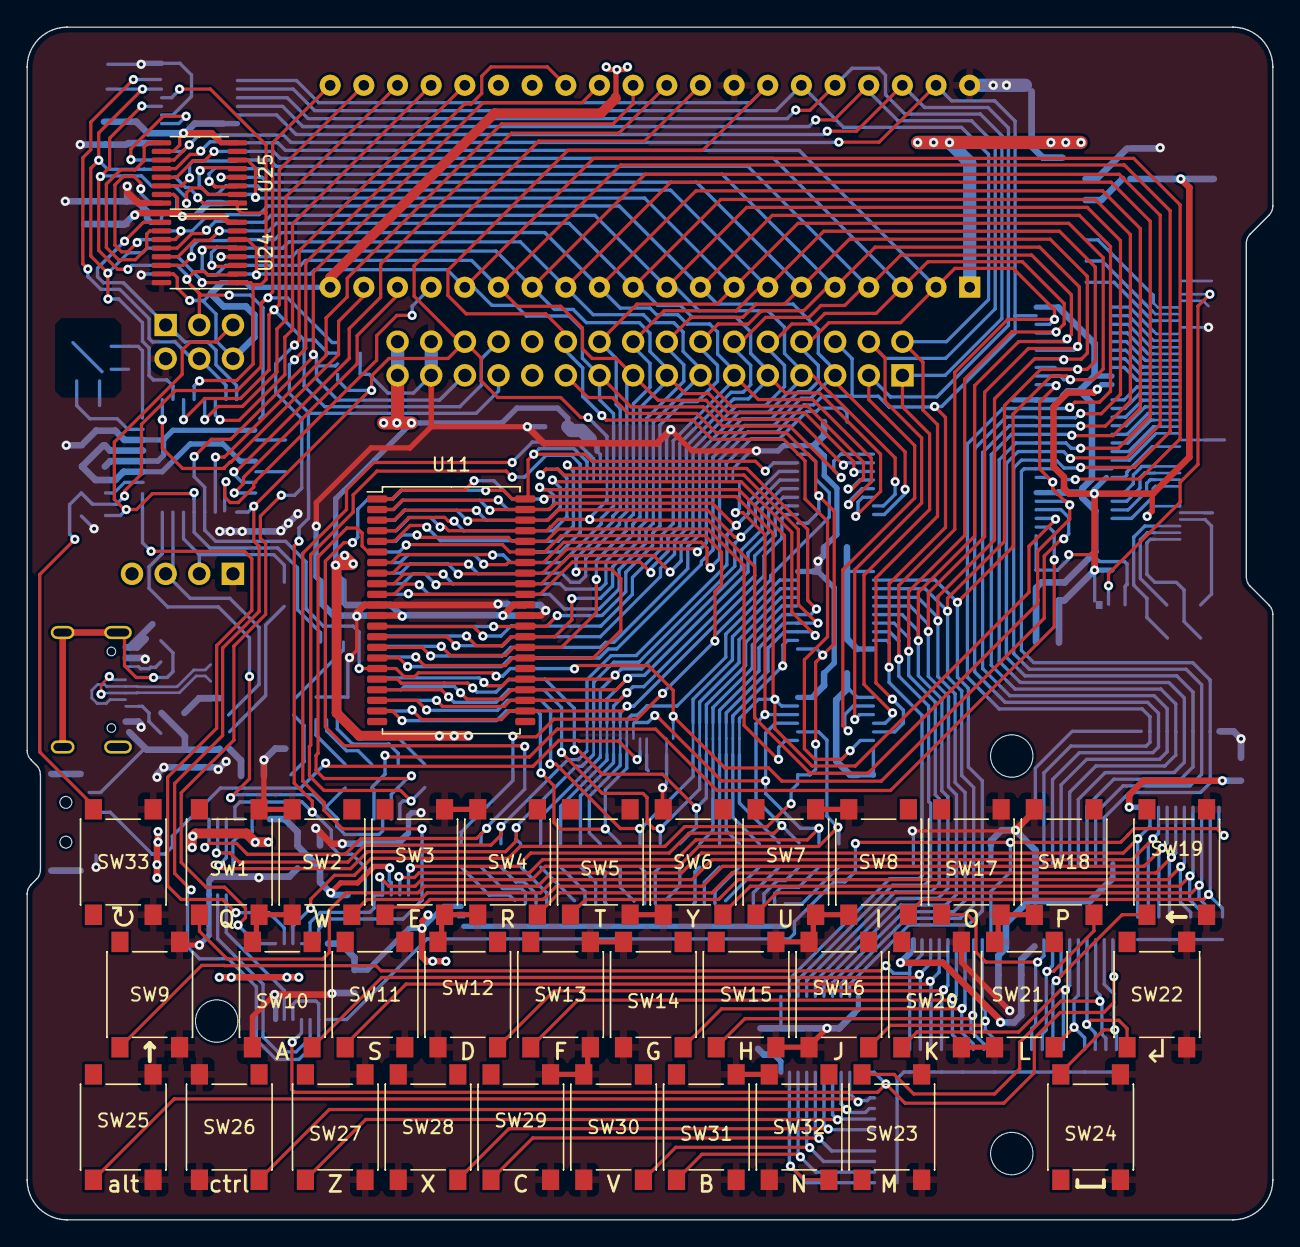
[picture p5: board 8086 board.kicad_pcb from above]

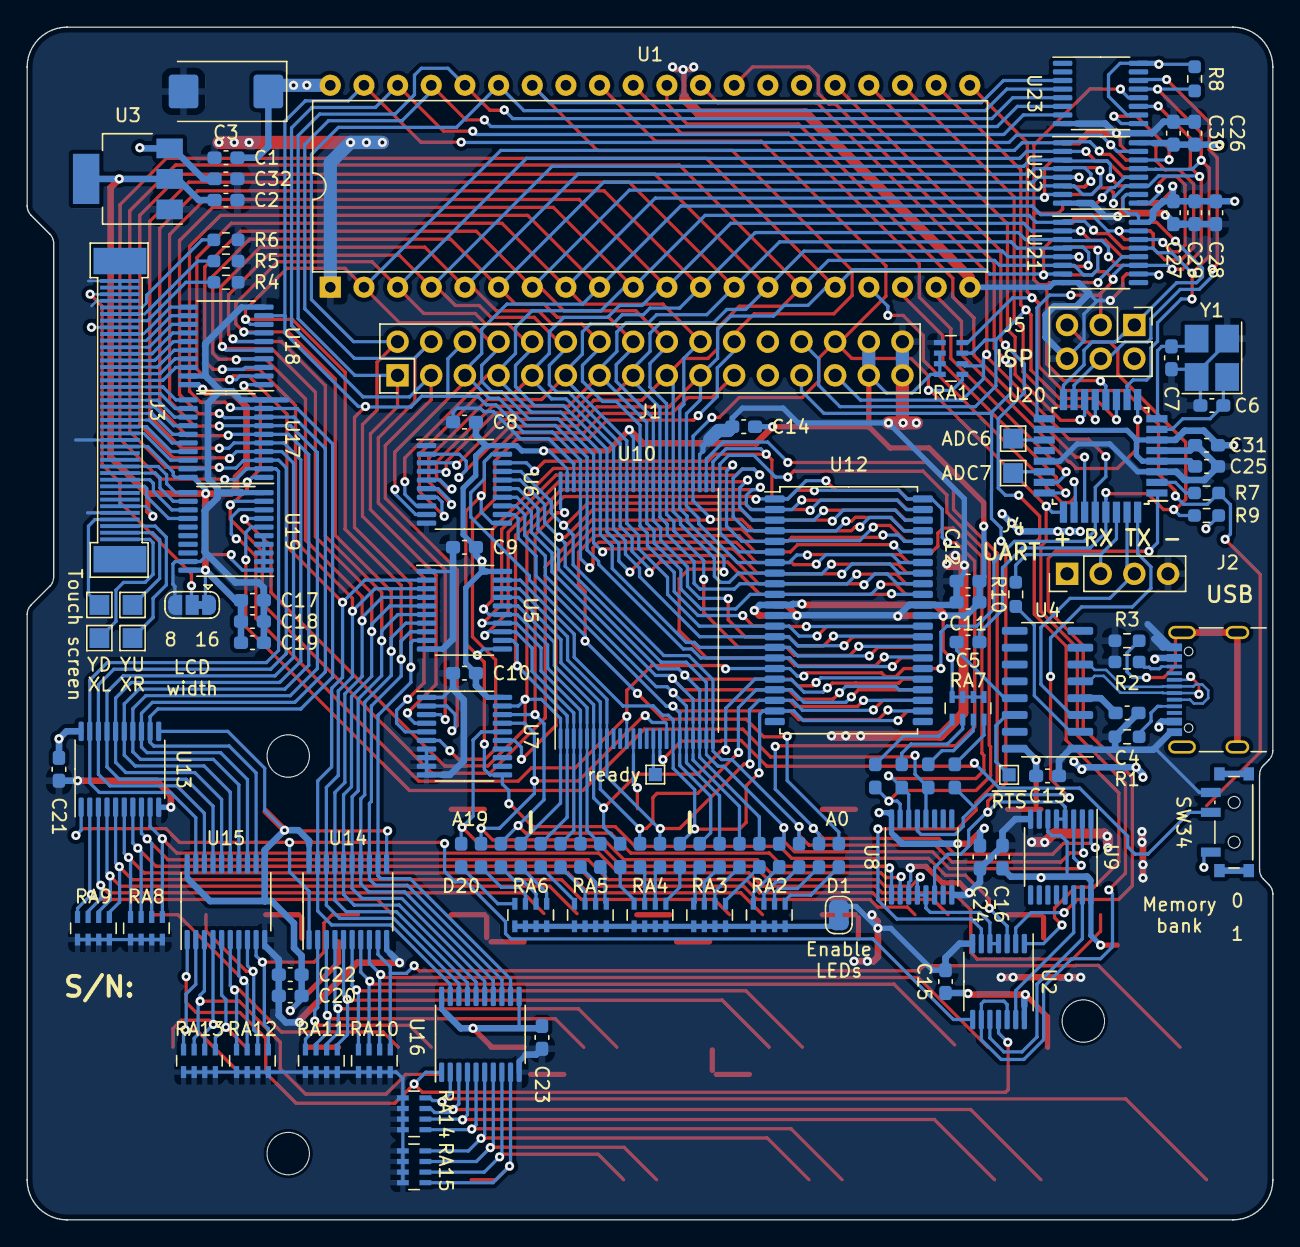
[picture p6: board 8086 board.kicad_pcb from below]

Board: 2 copper layers, 94.0 x 90.0 mm, 159 parts (123 on the bottom side), 181 nets.

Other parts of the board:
C4: 1uF; C_0603_1608Metric_Pad1.08x0.95mm_HandSolder
TP3: XL; TestPoint_Pad_1.5x1.5mm
TP4: YU; TestPoint_Pad_1.5x1.5mm
TP5: XR; TestPoint_Pad_1.5x1.5mm
TP6: YD; TestPoint_Pad_1.5x1.5mm
TP7: ADC6; TestPoint_Pad_1.5x1.5mm
TP8: ADC7; TestPoint_Pad_1.5x1.5mm
U4: CH340C; SOIC-16_3.9x9.9mm_P1.27mm

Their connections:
+5V: U4.16 (VCC); also elsewhere on the board
/Microcontroller/DN: U4.6 (UD-); also elsewhere on the board
/Microcontroller/DP: U4.5 (UD+); also elsewhere on the board
/Microcontroller/RX: U4.3 (RXD); also elsewhere on the board
GND: C4.1, U4.1 (GND); also elsewhere on the board
unnamed 155: U4.2 (TXD); also elsewhere on the board
unnamed: C4.2, U4.4 (V3)
unnamed 157: U4.13 (~DTR); also elsewhere on the board

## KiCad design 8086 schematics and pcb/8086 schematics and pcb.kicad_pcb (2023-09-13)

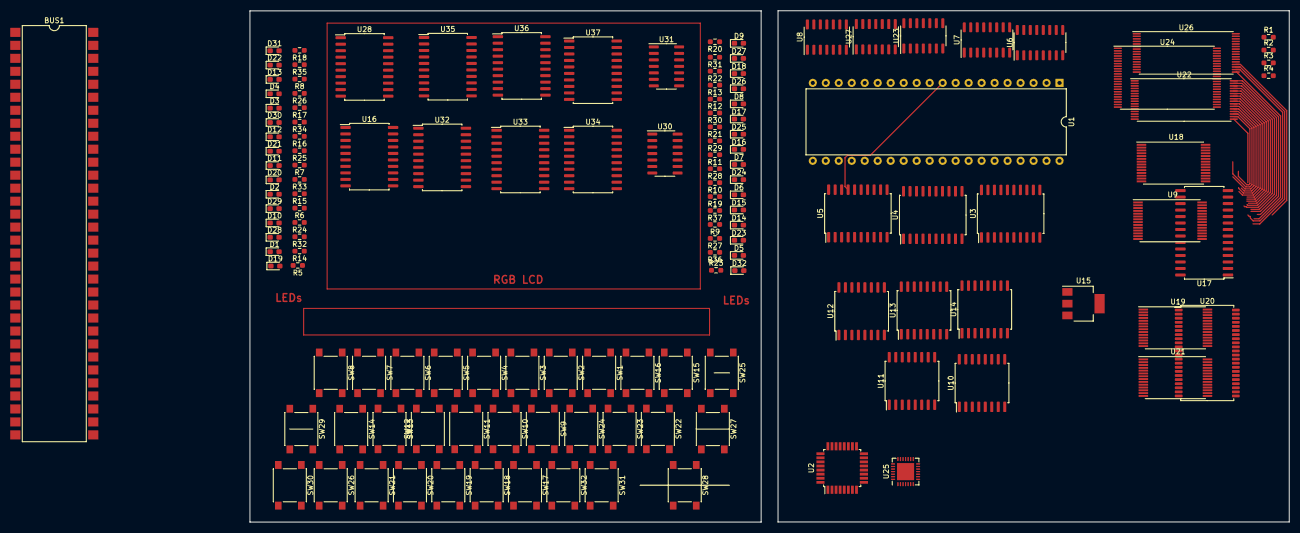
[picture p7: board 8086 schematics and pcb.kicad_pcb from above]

Board: 2 copper layers, 203.3 x 100.0 mm, 138 parts (0 on the bottom side), 198 nets.

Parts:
BUS1: 8086 BUS; SMDIP-64_W15.24mm
D1, D2, D3, D4, D5, D6, D7, D8, D9, D10, D11, D12, D13, D14, D15, D16, D17, D18, D19, D20, D21, D22, D23, D24, D25, D26, D27, D28, D29, D30, D31, D32: LED_Filled; LED_0603_1608Metric_Pad1.05x0.95mm_HandSolder
R1, R2, R3, R4: 10K; R_0603_1608Metric_Pad0.98x0.95mm_HandSolder
R5, R6, R7, R8, R9, R10, R11, R12, R13, R14, R15, R16, R17, R18, R19, R20, R21, R22, R23, R24, R25, R26, R27, R28, R29, R30, R31, R32, R33, R34, R35, R36, R37: R_US; R_0603_1608Metric_Pad0.98x0.95mm_HandSolder
SW1, SW2, SW3, SW4, SW5, SW6, SW7, SW8, SW9, SW10, SW11, SW12, SW13, SW14, SW15, SW16, SW17, SW18, SW19, SW20, SW21, SW22, SW23, SW24, SW25, SW26, SW27, SW28, SW29, SW30, SW31, SW32: SW_Push; SW_Push_1P1T_NO_6x6mm_H9.5mm
U1: P8086-2; DIP-40_W15.24mm
U2: ATmega328P-A; TQFP-32_7x7mm_P0.8mm
U3, U4, U5: 74HC373; SOIC-20W_7.5x12.8mm_P1.27mm
U6, U7: 74LS138; SOIC-16_3.9x9.9mm_P1.27mm
U8, U30: 74AC00; SOIC-14_3.9x8.7mm_P1.27mm
U9, U18, U19, U21: IS61C256AH; TSOP-I-28_11.8x8mm_P0.55mm
U10, U11, U12: 74HC595; SOIC-16W_7.5x10.3mm_P1.27mm
U13, U14: 74HC165; SOIC-16W_7.5x10.3mm_P1.27mm
U15: AMS1117-3.3; SOT-223-3_TabPin2
U16, U28, U32, U33, U34, U35, U36, U37: 74AC373; SOIC-20W_7.5x12.8mm_P1.27mm
U17: CXK58257AM; SOIC-28W_7.5x17.9mm_P1.27mm
U20: IS61C3216; TSOP-II-44_10.16x18.41mm_P0.8mm
U22, U26: AM29F002; TSOP-I-32_18.4x8mm_P0.5mm
U23: 74HC14; SOIC-14_3.9x8.7mm_P1.27mm
U24: 28F400; TSOP-I-48_18.4x12mm_P0.5mm
U25: CP2102N-Axx-xQFN28; QFN-28-1EP_5x5mm_P0.5mm_EP3.35x3.35mm
U27, U31: 74HC02; SOIC-14_3.9x8.7mm_P1.27mm

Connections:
+3.3V: BUS1.43 (3V3), BUS1.44 (3V3), U15.2 (VO)
+5V: BUS1.41 (5V), BUS1.42 (5V), R1.1, R2.1, R3.1, R4.1, SW1.1, SW2.1, SW3.1, SW4.1, SW5.1, SW6.1, SW7.1, SW8.1, SW9.1, SW10.1, SW11.1, SW12.1, SW13.1, SW14.1, SW15.1, SW16.1, SW17.1, SW18.1, SW19.1, SW20.1, SW21.1, SW22.1, SW23.1, SW24.1, SW25.1, SW26.1, SW27.1, SW28.1, SW29.1, SW30.1, SW31.1, SW32.1, U1.33 (NM/~MX), U1.40 (V_{CC}), U2.4 (VCC), U2.6 (VCC), U2.18 (AVCC), U3.20 (VCC), U4.20 (VCC), U5.20 (VCC), U6.6 (E3), U6.16 (VCC), U7.16 (VCC), U8.14 (V_{CC}), U9.28 (V_{CC}), U10.16 (VCC), U11.16 (VCC), U12.16 (VCC), U13.16 (V_{CC}), U14.16 (V_{CC}), U15.3 (VI), U16.20 (VCC), U17.28 (V_{CC}), U18.28 (V_{CC}), U19.28 (V_{CC}), U20.11 (V_{CC}), U20.33 (V_{CC}), U21.28 (V_{CC}), U22.8 (V_{CC}), U22.9 (~RESET), U23.14 (V_{CC}), U24.12 (~RP), U24.13 (V_{PP}), U24.14 (~WP), U24.37 (V_{CC}), U24.47 (~BYTE), U26.8 (V_{CC}), U26.9 (~RESET), U27.14 (V_{CC}), U28.20 (VCC), U30.14 (V_{CC}), U31.14 (V_{CC}), U32.20 (VCC), U33.20 (VCC), U34.20 (VCC), U35.20 (VCC), U36.20 (VCC), U37.20 (VCC)
/8086 Module - 1/ALE: U3.11 (LE), U4.11 (LE), U5.11 (LE), U23.12
/8086 Module - 1/CPUALE: U1.25 (ALE), U27.2
/8086 Module - 1/LA0: U5.2 (O0), U20.39 (~LB), U23.1
/8086 Module - 1/LA1: U5.5 (O1), U6.1 (A0), U9.10 (A0), U17.10 (A0), U18.10 (A0), U19.10 (A0), U20.44 (A0), U21.10 (A0), U22.20 (A0), U24.25 (A0), U26.20 (A0)
/8086 Module - 1/LA2: U5.6 (O2), U6.2 (A1), U9.9 (A1), U17.9 (A1), U18.9 (A1), U19.9 (A1), U20.43 (A1), U21.9 (A1), U22.19 (A1), U24.24 (A1), U26.19 (A1)
/8086 Module - 1/LA3: U5.9 (O3), U6.3 (A2), U9.8 (A2), U17.8 (A2), U18.8 (A2), U19.8 (A2), U20.42 (A2), U21.8 (A2), U22.18 (A2), U24.23 (A2), U26.18 (A2)
/8086 Module - 1/LA4: U5.12 (O4), U9.7 (A3), U17.7 (A3), U18.7 (A3), U19.7 (A3), U20.27 (A3), U21.7 (A3), U22.17 (A3), U24.22 (A3), U26.17 (A3)
/8086 Module - 1/LA5: U5.15 (O5), U9.6 (A4), U17.6 (A4), U18.6 (A4), U19.6 (A4), U20.26 (A4), U21.6 (A4), U22.16 (A4), U24.21 (A4), U26.16 (A4)
/8086 Module - 1/LA6: U5.16 (O6), U9.5 (A5), U17.5 (A5), U18.5 (A5), U19.5 (A5), U20.25 (A5), U21.5 (A5), U22.15 (A5), U24.20 (A5), U26.15 (A5)
/8086 Module - 1/LA7: U5.19 (O7), U9.4 (A6), U17.4 (A6), U18.4 (A6), U19.4 (A6), U20.24 (A6), U21.4 (A6), U22.14 (A6), U24.19 (A6), U26.14 (A6)
/8086 Module - 1/LA8: U3.2 (O0), U9.3 (A7), U17.3 (A7), U18.3 (A7), U19.3 (A7), U20.21 (A7), U21.3 (A7), U22.13 (A7), U24.18 (A7), U26.13 (A7)
/8086 Module - 1/LA9: U3.5 (O1), U9.25 (A8), U17.25 (A8), U18.25 (A8), U19.25 (A8), U20.20 (A8), U21.25 (A8), U22.3 (A8), U24.8 (A8), U26.3 (A8)
/8086 Module - 1/LA10: U3.6 (O2), U9.24 (A9), U17.24 (A9), U18.24 (A9), U19.24 (A9), U20.19 (A9), U21.24 (A9), U22.2 (A9), U24.7 (A9), U26.2 (A9)
/8086 Module - 1/LA11: U3.9 (O3), U9.21 (A10), U17.21 (A10), U18.21 (A10), U19.21 (A10), U20.18 (A10), U21.21 (A10), U22.31 (A10), U24.6 (A10), U26.31 (A10)
/8086 Module - 1/LA12: U3.12 (O4), U9.23 (A11), U17.23 (A11), U18.23 (A11), U19.23 (A11), U20.5 (A11), U21.23 (A11), U22.1 (A11), U24.5 (A11), U26.1 (A11)
/8086 Module - 1/LA13: U3.15 (O5), U9.2 (A12), U17.2 (A12), U18.2 (A12), U19.2 (A12), U20.4 (A12), U21.2 (A12), U22.12 (A12), U24.4 (A12), U26.12 (A12)
/8086 Module - 1/LA14: U3.16 (O6), U9.26 (A13), U17.26 (A13), U18.26 (A13), U19.26 (A13), U20.3 (A13), U21.26 (A13), U22.4 (A13), U24.3 (A13), U26.4 (A13)
/8086 Module - 1/LA15: U3.19 (O7), U9.1 (A14), U17.1 (A14), U18.1 (A14), U19.1 (A14), U20.2 (A14), U21.1 (A14), U22.5 (A14), U24.2 (A14), U26.5 (A14)
/8086 Module - 1/LA16: U4.2 (O0), U7.1 (A0), U22.11 (A15), U24.1 (A15), U26.11 (A15)
/8086 Module - 1/LA17: U4.5 (O1), U7.2 (A1), U22.10 (A16), U24.48 (A16), U26.10 (A16)
/8086 Module - 1/LA18: U4.6 (O2), U7.3 (A2), U22.6 (A17), U24.17 (A17), U26.6 (A17)
/8086 Module - 1/LA19: U4.9 (O3), U7.4 (~E1), U7.5 (~E2), U23.3
/8086 Module - 1/LBHE: U8.5, U8.13, U23.10
/8086 Module - 1/M/~IO: U1.28 (M/~IO), U6.4 (~E1), U6.5 (~E2), U7.6 (E3)
/8086 Module - 1/SEG0: U8.2, U8.4, U23.8
/8086 Module - 1/~LA0: U8.1, U8.9, U23.2
/8086 Module - 1/~LA19: U23.4, U24.26 (~CE)
/8086 Module - 1/~LBHE: U4.12 (O4), U20.40 (~UB), U23.11
/8086 Module - 1/~SEG0: U7.15 (~O0), U23.9
/8086 Module - 1/~SEG1: U7.14 (~O1), U20.6 (~CE), U23.5
/8086 Module - 2/~MEM1H: U8.11, U21.20 (~CE), U26.30 (~CE)
/8086 Module - 2/~MEM1L: U8.8, U19.20 (~CE), U22.30 (~CE)
/8086 Module - 2/~SEG0H: U8.6, U18.20 (~CE)
/8086 Module - 2/~SEG0L: U8.3, U9.20 (~CE), U17.20 (~CE)
/8086 Module - 2/~WRP: U22.7 (~WE), U24.11 (~WE), U26.7 (~WE)
/IO Module/WR0: U28.11 (LE), U31.10, U35.11 (LE)
/IO Module/WR1: U31.13, U36.11 (LE), U37.11 (LE)
/IO Module/~RD0: U16.1 (~OE), U30.3, U32.1 (~OE)
/IO Module/~RD1: U30.6, U33.1 (~OE), U34.1 (~OE)
/Microcontroller Module/REG_OE: U2.23 (PC0), U10.13 (~OE), U11.13 (~OE), U12.13 (~OE)
/Microcontroller Module/REG_RCLK: U2.14 (PB2), U10.12 (RCLK), U11.12 (RCLK), U12.12 (RCLK)
/Microcontroller Module/REG_SHLD: U2.24 (PC1), U13.1 (SH/~LD), U14.1 (SH/~LD)
/Microcontroller Module/SPI_MISO: U2.16 (PB4), U14.9 (QH)
/Microcontroller Module/SPI_MOSI: U2.15 (PB3), U10.14 (SER)
/Microcontroller Module/SPI_SCK: U2.17 (PB5), U10.11 (SRCLK), U11.11 (SRCLK), U12.11 (SRCLK)
A16: BUS1.17 (A16), U1.38 (A16), U4.3 (D0), U12.15 (QA)
A17: BUS1.18 (A17), U1.37 (A17), U4.4 (D1), U12.1 (QB)
A18: BUS1.19 (A18), U1.36 (A18), U4.7 (D2), U12.2 (QC)
A19: BUS1.20 (A19), U1.35 (A19), U4.8 (D3), U12.3 (QD)
AD0: BUS1.1 (AD0), U1.16 (AD0), U5.3 (D0), U9.11 (I/O0), U10.15 (QA), U13.11 (A), U16.2 (O0), U17.11 (I/O0), U19.11 (I/O0), U20.7 (I/O0), U22.21 (DQ0), U24.29 (DQ0), U28.3 (D0), U33.2 (O0), U36.3 (D0)
AD1: BUS1.2 (AD1), BUS1.3 (AD2), U1.15 (AD1), U5.4 (D1), U9.12 (I/O1), U10.1 (QB), U13.12 (B), U16.5 (O1), U17.12 (I/O1), U19.12 (I/O1), U20.8 (I/O1), U22.22 (DQ1), U24.31 (DQ1), U28.4 (D1), U33.5 (O1), U36.4 (D1)
AD2: U1.14 (AD2), U5.7 (D2), U9.13 (I/O2), U10.2 (QC), U13.13 (C), U16.6 (O2), U17.13 (I/O2), U19.13 (I/O2), U20.9 (I/O2), U22.23 (DQ2), U24.33 (DQ2), U28.7 (D2), U33.6 (O2), U36.7 (D2)
AD3: BUS1.4 (AD3), U1.13 (AD3), U5.8 (D3), U9.15 (I/O3), U10.3 (QD), U13.14 (D), U16.9 (O3), U17.15 (I/O3), U19.15 (I/O3), U20.10 (I/O3), U22.25 (DQ3), U24.35 (DQ3), U28.8 (D3), U33.9 (O3), U36.8 (D3)
AD4: BUS1.5 (AD4), U1.12 (AD4), U5.13 (D4), U9.16 (I/O4), U10.4 (QE), U13.3 (E), U16.12 (O4), U17.16 (I/O4), U19.16 (I/O4), U20.13 (I/O4), U22.26 (DQ4), U24.38 (DQ4), U28.13 (D4), U33.12 (O4), U36.13 (D4)
AD5: BUS1.6 (AD5), U1.11 (AD5), U5.14 (D5), U9.17 (I/O5), U10.5 (QF), U13.4 (F), U16.15 (O5), U17.17 (I/O5), U19.17 (I/O5), U20.14 (I/O5), U22.27 (DQ5), U24.40 (DQ5), U28.14 (D5), U33.15 (O5), U36.14 (D5)
AD6: BUS1.7 (AD6), U1.10 (AD6), U5.17 (D6), U9.18 (I/O6), U10.6 (QG), U13.5 (G), U16.16 (O6), U17.18 (I/O6), U19.18 (I/O6), U20.15 (I/O6), U22.28 (DQ6), U24.42 (DQ6), U28.17 (D6), U33.16 (O6), U36.17 (D6)
AD7: BUS1.8 (AD7), U1.9 (AD7), U5.18 (D7), U9.19 (I/O7), U10.7 (QH), U13.6 (H), U16.19 (O7), U17.19 (I/O7), U19.19 (I/O7), U20.16 (I/O7), U22.29 (DQ7), U24.44 (DQ7), U28.18 (D7), U33.19 (O7), U36.18 (D7)
AD8: BUS1.9 (AD8), U1.8 (AD8), U3.3 (D0), U11.15 (QA), U14.11 (A), U18.11 (I/O0), U20.29 (I/O8), U21.11 (I/O0), U24.30 (DQ8), U26.21 (DQ0), U32.2 (O0), U34.2 (O0), U35.3 (D0), U37.3 (D0)
AD9: BUS1.10 (AD9), U1.7 (AD9), U3.4 (D1), U11.1 (QB), U14.12 (B), U18.12 (I/O1), U20.30 (I/O9), U21.12 (I/O1), U24.32 (DQ9), U26.22 (DQ1), U32.5 (O1), U34.5 (O1), U35.4 (D1), U37.4 (D1)
AD10: BUS1.11 (AD10), U1.6 (AD10), U3.7 (D2), U11.2 (QC), U14.13 (C), U18.13 (I/O2), U20.31 (I/O10), U21.13 (I/O2), U24.34 (DQ10), U26.23 (DQ2), U32.6 (O2), U34.6 (O2), U35.7 (D2), U37.7 (D2)
AD11: BUS1.12 (AD11), U1.5 (AD11), U3.8 (D3), U11.3 (QD), U14.14 (D), U18.15 (I/O3), U20.32 (I/O11), U21.15 (I/O3), U24.36 (DQ11), U26.25 (DQ3), U32.9 (O3), U34.9 (O3), U35.8 (D3), U37.8 (D3)
AD12: BUS1.13 (AD12), U1.4 (AD12), U3.13 (D4), U11.4 (QE), U14.3 (E), U18.16 (I/O4), U20.35 (I/O12), U21.16 (I/O4), U24.39 (DQ12), U26.26 (DQ4), U32.12 (O4), U34.12 (O4), U35.13 (D4), U37.13 (D4)
AD13: BUS1.14 (AD13), U1.3 (AD13), U3.14 (D5), U11.5 (QF), U14.4 (F), U18.17 (I/O5), U20.36 (I/O13), U21.17 (I/O5), U24.41 (DQ13), U26.27 (DQ5), U32.15 (O5), U34.15 (O5), U35.14 (D5), U37.14 (D5)
AD14: BUS1.15 (AD14), U1.2 (AD14), U3.17 (D6), U11.6 (QG), U14.5 (G), U18.18 (I/O6), U20.37 (I/O14), U21.18 (I/O6), U24.43 (DQ14), U26.28 (DQ6), U32.16 (O6), U34.16 (O6), U35.17 (D6), U37.17 (D6)
AD15: BUS1.16 (AD15), U1.39 (AD15), U3.18 (D7), U11.7 (QH), U14.6 (H), U18.19 (I/O7), U20.38 (I/O15), U21.19 (I/O7), U24.45 (DQ15), U26.29 (DQ7), U32.19 (O7), U34.19 (O7), U35.18 (D7), U37.18 (D7)
BUSALE: BUS1.22 (ALE), U2.2 (PD4), U27.3
CLK: BUS1.40 (CLK), U1.19 (CLK), U2.9 (PD5)
GND: BUS1.47 (GND), BUS1.48 (GND), R5.2, R6.2, R7.2, R8.2, R9.2, R10.2, R11.2, R12.2, R13.2, R14.2, R15.2, R16.2, R17.2, R18.2, R19.2, R20.2, R21.2, R22.2, R23.2, R24.2, R25.2, R26.2, R27.2, R28.2, R29.2, R30.2, R31.2, R32.2, R33.2, R34.2, R35.2, R36.2, R37.2, U1.1 (GND), U1.20 (GND), U2.3 (GND), U2.5 (GND), U2.21 (GND), U3.1 (~OE), U3.10 (GND), U4.1 (~OE), U4.10 (GND), U5.1 (~OE), U5.10 (GND), U6.8 (GND), U7.8 (GND), U8.7 (GND), U9.14 (GND), U10.8 (GND), U10.10 (~SRCLR), U11.8 (GND), U11.10 (~SRCLR), U12.8 (GND), U12.10 (~SRCLR), U13.8 (GND), U14.8 (GND), U15.1 (GND), U16.10 (GND), U17.14 (GND), U18.14 (GND), U19.14 (GND), U20.12 (GND), U20.34 (GND), U21.14 (GND), U22.24 (GND), U23.7 (GND), U24.27 (GND), U24.46 (GND), U26.24 (GND), U27.7 (GND), U28.1 (~OE), U28.10 (GND), U30.7 (GND), U31.7 (GND), U32.10 (GND), U33.10 (GND), U34.10 (GND), U35.1 (~OE), U35.10 (GND), U36.1 (~OE), U36.10 (GND), U37.1 (~OE), U37.10 (GND)
HLDA: BUS1.38 (HLDA), U1.30 (HLDA), U2.13 (PB1)
HOLD: BUS1.37 (HOLD), U1.31 (HOLD), U2.12 (PB0)
INTR: BUS1.35 (INTR), U1.18 (INTR), U2.25 (PC2)
NMI: BUS1.34 (NMI), U1.17 (NMI), U2.26 (PC3)
unnamed: D1.2 (A), U28.5 (O1)
unnamed: D1.1 (K), R11.1
unnamed: D2.2 (A), U28.6 (O2)
unnamed: D2.1 (K), R10.1
unnamed: D3.2 (A), U28.2 (O0)
unnamed: D3.1 (K), R12.1
unnamed: D4.2 (A), U28.9 (O3)
unnamed: D4.1 (K), R5.1
unnamed: D5.2 (A), U28.12 (O4)
unnamed: D5.1 (K), R6.1
unnamed: D6.2 (A), U28.15 (O5)
unnamed: D6.1 (K), R7.1
unnamed: D7.2 (A), U28.16 (O6)
unnamed: D7.1 (K), R8.1
unnamed: D8.2 (A), U28.19 (O7)
unnamed: D8.1 (K), R9.1
unnamed: D9.2 (A), U35.2 (O0)
unnamed: D9.1 (K), R13.1
unnamed: D10.2 (A), U35.12 (O4)
unnamed: D10.1 (K), R17.1
unnamed: D11.2 (A), U35.5 (O1)
unnamed: D11.1 (K), R14.1
unnamed: D12.2 (A), U35.15 (O5)
unnamed: D12.1 (K), R18.1
unnamed: D13.2 (A), U35.6 (O2)
unnamed: D13.1 (K), R15.1
unnamed: D14.2 (A), U35.16 (O6)
unnamed: D14.1 (K), R19.1
unnamed: D15.2 (A), U35.9 (O3)
unnamed: D15.1 (K), R16.1
unnamed: D16.2 (A), U35.19 (O7)
unnamed: D16.1 (K), R20.1
unnamed: D17.2 (A), U36.2 (O0)
unnamed: D17.1 (K), R21.1
unnamed: D18.2 (A), U36.12 (O4)
unnamed: D18.1 (K), R25.1
unnamed: D19.2 (A), U36.5 (O1)
unnamed: D19.1 (K), R22.1
unnamed: D20.2 (A), U36.15 (O5)
unnamed: D20.1 (K), R26.1
unnamed: D21.2 (A), U36.6 (O2)
unnamed: D21.1 (K), R23.1
unnamed: D22.2 (A), U36.16 (O6)
unnamed: D22.1 (K), R27.1
unnamed: D23.2 (A), U36.9 (O3)
unnamed: D23.1 (K), R24.1
unnamed: D24.2 (A), U36.19 (O7)
unnamed: D24.1 (K), R28.1
unnamed: D25.2 (A), U37.2 (O0)
unnamed: D25.1 (K), R29.1
unnamed: D26.2 (A), U37.12 (O4)
unnamed: D26.1 (K), R33.1
unnamed: D27.2 (A), U37.5 (O1)
unnamed: D27.1 (K), R30.1
unnamed: D28.2 (A), U37.15 (O5)
unnamed: D28.1 (K), R34.1
unnamed: D29.2 (A), U37.6 (O2)
unnamed: D29.1 (K), R31.1
unnamed: D30.2 (A), U37.16 (O6)
unnamed: D30.1 (K), R35.1
unnamed: D31.2 (A), U37.9 (O3)
unnamed: D31.1 (K), R32.1
unnamed: D32.2 (A), U37.19 (O7)
unnamed: D32.1 (K), R36.1
unnamed: U8.10, U8.12
unnamed: U16.11 (LE), U32.11 (LE), U33.11 (LE), U34.11 (LE)
unnamed: U10.9 (QH'), U11.14 (SER)
unnamed: U11.9 (QH'), U12.14 (SER)
unnamed: SW1.2, U16.3 (D0)
unnamed: SW2.2, U16.4 (D1)
unnamed: SW3.2, U16.7 (D2)
unnamed: SW4.2, U16.8 (D3)
unnamed: SW5.2, U16.13 (D4)
unnamed: SW6.2, U16.14 (D5)
unnamed: SW7.2, U16.17 (D6)
unnamed: R37.1, SW8.2, U16.18 (D7)
unnamed: U23.13, U27.1
unnamed: U30.1, U30.2, U31.1
unnamed: U30.4, U30.5, U31.4
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

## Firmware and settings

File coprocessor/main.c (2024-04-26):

#include <stdio.h>
#include <avr/interrupt.h>
#include <util/delay.h>

#include "clock.h"
#include "uart.h"
#include "isp.h"
#include "bus.h"

#include "spi.h"

#define FIRMWARE_VERSION    0x0100
#ifndef DEVICE_ID
	#error DEVICE_ID must be define externally
#endif

/* TODO list:
 - work on spi.c and spi.h (currently ad_get or ad_set or both are stuck)
 - work on python utility!
*/


/** //////////////
 * @brief 
 * 
 * 8086 interrupt types are:
 * 	0 - divided by 0
 * 	1 - if TF (trap flag) is set - single step execution
 * 	2 - NMI
 * 	3 - INT3, meant for calling the debugger
 * 	4 - INTO (interrupt if OF flag is set)
 * internal interrupts ("INT 123" for example) cannot be turned off.
 * interrupts 0-31 are supposedly 'reserved'
 * 
 * 
 * @param interrupt_number 
 */
void generate_interrupt(uint8_t interrupt_number){
	// M/IO is low during interrupt number reading
	// and since 8086 has ownership of the bus, M/IO must be 0 to prevent a short circuit.
	// also, during interrupt acknowledge, A16-A19 do not float!,
	// so they must be set to 0 to prevent short circuits.
	// TODO check that's true and that there are no shorts caused. maybe they stay the same as the previous address addressed.

	GPIO_OUTPUT_LOW(INTR);  //needed for some reason... shouldn't be as its already called in main... XXX
	GPIO_SET_OUTPUT(INTR); //

	GPIO_SET_INPUT(INTA_N);
	GPIO_OUTPUT_LOW(INTA_N);

	// ad_set(0x00000000 | interrupt_number);
	GPIO_OUTPUT_HIGH(INTR);
	while(GPIO_GET_INPUT(INTA_N));
	GPIO_OUTPUT_LOW(INTR);
	while(!GPIO_GET_INPUT(INTA_N));
	// GPIO_OUTPUT_LOW(REG_OE_N);
	while(GPIO_GET_INPUT(INTA_N));
	GPIO_OUTPUT_LOW(REG_OE_N); // try moving this before previous while
	while(!GPIO_GET_INPUT(INTA_N));
	GPIO_OUTPUT_HIGH(REG_OE_N);
}

void generate_nmi(void){
	GPIO_OUTPUT_LOW(NMI);  //needed for some reason... shouldn't be as its already called in main... XXX
	GPIO_SET_OUTPUT(NMI); //
	GPIO_OUTPUT_HIGH(NMI);
	while(GPIO_GET_INPUT(CLK));

	while(!GPIO_GET_INPUT(CLK));
	while(GPIO_GET_INPUT(CLK)); //NMI should be on for at

	while(!GPIO_GET_INPUT(CLK));
	while(GPIO_GET_INPUT(CLK)); //least two clock cycles
	
	GPIO_OUTPUT_LOW(NMI);
}

// TODO check this:
/*
ISR(PCINT1_vect){
	return;
	uint16_t address, data;
	GPIO_OUTPUT_LOW(READY);
	address = ad_get();
	int t = 0;
	while(t<100){
		if(!GPIO_GET_INPUT(WR_N)){ //write
			//address is not valid!. maybe if i hand insert the LD pulse before any (automatically generated) prologue code
			data = ad_get();
			printf("wr %x\n", data);
			GPIO_OUTPUT_HIGH(READY);
			break;
		}else if(!GPIO_GET_INPUT(RD_N)){ //read
			char *str = "this is a test string message!";
			//can take as much time as i want to...
			if(address >= 30) ad_set(0);
			else ad_set((str[(address & ~1)+1] << 8) | str[(address & ~1)]);
			GPIO_OUTPUT_LOW(REG_OE_N);
			GPIO_OUTPUT_HIGH(READY);
			while(!GPIO_GET_INPUT(RD_N));
			GPIO_OUTPUT_HIGH(REG_OE_N);
			break;
		}
		t++;
	}
}
*/








/**
 * @brief Preforms 8086 reset sequence, and wait for bus hold acknowledgment.
 * 
 * This will immediately hold the bus after reset, to prevent any instruction from executing.
 * See "PROCESSOR RESET AND INITIALIZATION" on page 10 of 8086 datasheet.
 * 
 * @note A clock signal should be present for the reset sequence to work properly,
 * since after reset, it take a few clock cycles for status lines to float to 3-state,
 * and for bus hold to be acknowledged.
 */
void reset_sequence(void){
	// request hold and reset 8086:
	GPIO_OUTPUT_HIGH(RESET);
	GPIO_OUTPUT_HIGH(HOLD);
	_delay_ms(200); // this depends on the clock speed. 200ms should be good down to about 50Hz clock.
	// on a fast clock, 20us should be enough.
	GPIO_OUTPUT_LOW(RESET);
	// wait for hold acknowledge:
	while(GPIO_GET_INPUT(HLDA) == 0);
}

/**
 * @brief Initalizes all GPIO pins. Leaves RESET as high.
 * 
 * AVR pins are all floating after reset, but 8086 pins are *not* all floating after reset.
 * So after reset, it must be assumed that the 8086 is the bus master, to avoid short circuits.
 * 
 */
void init_gpio(void){
	// coprocessor controlled signals:
	GPIO_OUTPUT_HIGH(RESET);
	GPIO_SET_OUTPUT(RESET);

	GPIO_OUTPUT_LOW(ALE);
	GPIO_SET_OUTPUT(ALE);

	GPIO_OUTPUT_LOW(TEST_N);
	GPIO_SET_OUTPUT(TEST_N);

	GPIO_OUTPUT_LOW(INTR);
	GPIO_SET_OUTPUT(INTR);

	GPIO_OUTPUT_LOW(NMI);
	GPIO_SET_OUTPUT(NMI);

	GPIO_OUTPUT_LOW(HOLD);
	GPIO_SET_OUTPUT(HOLD);
	
	GPIO_SET_INPUT(HLDA);
	GPIO_OUTPUT_LOW(HLDA);

	// it is unclear from datasheet and user family manual if INTA floats during bus hold or not.
	// since the coprocessor is the only one to read this signal, it doesn't matter.
	GPIO_SET_INPUT(INTA_N);
	GPIO_OUTPUT_HIGH(INTA_N);
	GPIO_SET_OUTPUT(INTA_N);

	// coprocessor controlled signals, only if its chip select is enabled:
	GPIO_SET_INPUT(READY);
	
	// bus master controlled signals:
	// all bus master lines will start as inputs. only on bus hold will they change to outputs.
	GPIO_SET_INPUT(RD_N);
	GPIO_SET_INPUT(WR_N);
	// M_IO and BHE also float, but they are controlled via the address shift registers.
}

int main(void){
	init_gpio(); // reset is high after this.
	UART_CONFIG(UART_1M_16MHZ);
	uart_enable_rx_interrupt();
	spi_config(SPI_CLOCK_RATE_PRESCALER_64); // spi_config(SPI_CLOCK_RATE_PRESCALER_2);
	sei();

	CLOCK_CONFIG(CLOCK_100k_HZ);
	reset_sequence();
	_delay_ms(100);

	printf("program started!!\n");

	// /*
	for(int i = 0; i < 5; i++){
		bus_release();
		_delay_us(20);
		bus_hold();
		_delay_ms(2000);
	}
	// */

	// /*
	cli();
	for(int t = 0; t < 20; t++){
		GPIO_OUTPUT_LOW(REG_OE_N);
		for(int i=0; i < 16; i++){
			printf("%d, ", i);
			ad_set((((uint32_t)i) << 16));
			GPIO_OUTPUT_HIGH(ALE);
			asm("NOP\r\n NOP\r\n NOP");
			GPIO_OUTPUT_LOW(ALE);
			_delay_ms(200);
		}
		for(int i=0; i<16; i++){
			printf("%d, ", i);
			ad_set((((uint32_t)i) << 16));
			GPIO_OUTPUT_HIGH(ALE);
			asm("NOP\r\n NOP\r\n NOP");
			GPIO_OUTPUT_LOW(ALE);
			_delay_ms(100);
		}
		GPIO_OUTPUT_HIGH(REG_OE_N);
	}
	// */
	while(1); // only responding to uart commands via interrupts
}


uint8_t isp_input_buffer[ISP_PACKET_MAX_PACKET_LENGTH];
uint16_t isp_input_buffer_index = 0;
uint16_t isp_input_packet_size = 0;

uint32_t parameter_write_address;
uint32_t parameter_clock_speed;
uint32_t parameter_uart_speed;
uint32_t parameter_reset_time;
uint32_t parameter_timeout;
uint32_t parameter_gpio_test;

/** //////////////////
 * @brief 
 * 
 * @param packet_id 
 * @param data_length 0-255
 * @param data can be NULL if data length is 0
 */
void responde(uint8_t packet_id, uint8_t data_length, uint8_t *data){
	uart_putchar(packet_id, NULL);
	uart_putchar(data_length, NULL);
	for(uint8_t i = 0; i < data_length; i++) uart_putchar(data[i], NULL);
}

void responde_0_is_256(uint8_t packet_id, uint8_t data_length, uint8_t *data){
	uart_putchar(packet_id, NULL);
	uart_putchar(data_length, NULL);
	uint8_t i = 0;
	do{
		uart_putchar(data[i++], NULL);
	}while(i != data_length);
}


void command_parameter_read(uint8_t *packet_data){
	uint8_t parameter = *packet_data;
	uint32_t data;
	switch(parameter){ // parameter_id to read
		case PARAMETER_DEVICE_ID:
			data = DEVICE_ID;
			break;
		case PARAMETER_FIRMWARE_VERSION:
			data = FIRMWARE_VERSION;
			break;
		case PARAMETER_PROTOCOL_VERSION:
			data = ISP_PROTOCOL_VERSION;
			break;
		case PARAMETER_WRITE_ADDRESS:
			data = parameter_write_address;
			break;
		case PARAMETER_CLOCK_SPEED:
			data = parameter_clock_speed;
			break;
		case PARAMETER_UART_SPEED:
			data = parameter_uart_speed;
			break;
		case PARAMETER_RESET_TIME:
			data = parameter_reset_time;
			break;
		case PARAMETER_TIMEOUT:
			data = parameter_timeout;
			break;
		case PARAMETER_GPIO_TEST:
			data = parameter_gpio_test;
			break;
		default:
			responde(INVALID_PARAMETER, 0, NULL);
			return;
	}
	responde(SUCCESS_READ_PARAMETER, 4, (uint8_t *)(&data));
}

void command_parameter_write(uint8_t *packet_data){
	uint8_t parameter = *packet_data;
	packet_data++;
	uint32_t data = *((uint32_t *)packet_data);
	switch(parameter){ // parameter_id to read
		case PARAMETER_DEVICE_ID:
			responde(FAILURE, 0, NULL);
			break;
		case PARAMETER_FIRMWARE_VERSION:
			responde(FAILURE, 0, NULL);
			break;
		case PARAMETER_WRITE_ADDRESS:
			parameter_write_address = data;
			break;
		case PARAMETER_CLOCK_SPEED:
			parameter_clock_speed = data;
			break;
		case PARAMETER_UART_SPEED:
			parameter_uart_speed = data;
			break;
		case PARAMETER_RESET_TIME:
			parameter_reset_time = data;
			break;
		case PARAMETER_TIMEOUT:
			parameter_timeout = data;
			break;
		case PARAMETER_GPIO_TEST:
			parameter_gpio_test = data;
			break;
		default:
			responde(INVALID_PARAMETER, 0, NULL);
			return;
	}
	responde(SUCCESS, 0, NULL);
}

void command_bus_read(uint8_t *packet_data){
	uint32_t address = *((uint32_t *)packet_data);
	packet_data += 4;
	uint16_t length = *packet_data;
	if(length == 0) length = 256; // 0 is 256
	uint8_t buffer[length];
	// printf("bus read of address %ld\n", address);
	uint8_t status = bus_read(address, length, buffer);
	// printf("left command bus read!");
	if(status == 0){
		responde_0_is_256(SUCCESS_READ, (uint8_t)length, buffer); // length converted from 256 back to 0
	}else{
		responde(FAILURE, 0, NULL);
	}
}

void command_bus_write(uint8_t *packet_data, uint16_t data_length){
	uint8_t status = bus_write(parameter_write_address, data_length, packet_data);
	if(status == 0) responde(SUCCESS, 0, NULL);
	else responde(FAILURE, 0, NULL);
}

void parse_packet(){
	uint8_t packet_id = isp_input_buffer[ISP_FIELD_INDEX_PACKET_ID];
	uint16_t data_length = isp_input_buffer[ISP_FIELD_INDEX_DATA_LENGTH];
	uint8_t *data = &isp_input_buffer[ISP_FIELD_INDEX_DATA_START];
	if((packet_id & ISP_DATA_RANGE_1_TO_256_FLAG) && data_length == 0) data_length = 256;  // 0 is 256 bytes

	switch(packet_id){
		case PARAMETER_READ:
			if(data_length != ISP_DATA_LENGTH_PARAMETER_READ) break;
			command_parameter_read(data);
			return;
		case PARAMETER_WRITE:
			if(data_length != ISP_DATA_LENGTH_PARAMETER_WRITE) break;
			command_parameter_write(data);
			return;
		case RESET_AND_BUS_HOLD:
			if(data_length != ISP_DATA_LENGTH_RESET_AND_HOLD_BUS) break;
			reset_sequence();
			responde(SUCCESS, 0, NULL);
			return;
		case BUS_HOLD:
			if(data_length != ISP_DATA_LENGTH_BUS_HOLD) break;
			bus_hold();
			responde(SUCCESS, 0, NULL);
			return;
		case BUS_RELEASE:
			if(data_length != ISP_DATA_LENGTH_BUS_RELEASE) break;
			bus_release();
			responde(SUCCESS, 0, NULL);
			return;
		case BUS_READ:
			if(data_length != ISP_DATA_LENGTH_BUS_READ) break;
			command_bus_read(data);
			return;
		case GENERATE_INTERRUPT:
			if(data_length != ISP_DATA_LENGTH_GENERATE_INTERRPUT) break;
			generate_interrupt(*data);
			responde(SUCCESS, 0, NULL);
			return;
		case GENERATE_NMI:
			if(data_length != ISP_DATA_LENGTH_GENERATE_NMI) break;
			generate_nmi();
			responde(SUCCESS, 0, NULL);
			return;
		case BUS_WRITE:
			command_bus_write(data, data_length);
			return;
		default:
			responde(INVALID_COMMAND, 0, NULL);
	}
	// if reached here, that mean packet has invalid length
	responde(INVALID_DATA_LENGTH, 0, NULL);
}

ISR(USART_RX_vect){
	uint8_t data = UDR0;
	if(isp_input_buffer_index == ISP_FIELD_INDEX_DATA_LENGTH){
		isp_input_packet_size = ISP_PACKET_HEADER_LENGTH + ISP_PACKET_FOOTER_LENGTH + data;
	}
	isp_input_buffer[isp_input_buffer_index++] = data;

	if(isp_input_buffer_index == isp_input_packet_size){ // entire packet was read
		parse_packet(); // parse received packet
		isp_input_buffer_index = 0;
		isp_input_packet_size = 0; // get ready to receive new packet
	}
}

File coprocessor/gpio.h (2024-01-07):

#ifndef GPIO_H_
#define GPIO_H_

/**
 * @brief Hardware defenition for which pin is what, as well as preprocessor directives for easy GPIO control.
 * 
 * This file maps all signals to their respective ports and pins,
 * enabling statments like GPIO_SET_OUTPUT(ALE) to translate into direct DDRx |= (1 << y).
 * Signal which are active low are marked with a '_N' suffix.
 * Some pins are not remappable and are guaranteed to be on that pin.
 * 
 * Information about proprocessor black magic at https://gcc.gnu.org/onlinedocs/cpp/Argument-Prescan.html.
 */

#include <avr/io.h>

#define XXDDR(X)                (DDR##X)
#define XDDR(X)                 (XXDDR(X))
#define DDR(X) 	                (XDDR(X##_PORT))
#define XXPORT(X)               (PORT##X)
#define XPORT(X)                (XXPORT(X))
#define PORT(X)                 (XPORT(X##_PORT))
#define XXPIN(X)                (PIN##X)
#define XPIN(X)                 (XXPIN(X))
#define PIN(X)                  (XPIN(X##_PORT))
#define BIT(X) 	                (X##_BIT)

/**
 * @brief Sets a signal as output.
 * @param X Signal name.
 */
#define GPIO_SET_OUTPUT(X)	    (DDR(X) 	|=  (1 << BIT(X)))
/**
 * @brief Sets a signal as input.
 * @param X Signal name.
 */
#define GPIO_SET_INPUT(X)	    (DDR(X) 	&= ~(1 << BIT(X)))
/**
 * @brief Sets a signal to output high. If signal is input, it will enable pull-up.
 * @param X Signal name.
 */
#define GPIO_OUTPUT_HIGH(X)		(PORT(X) |=  (1 << BIT(X)))
/**
 * @brief Sets a signal to output low. If signal pin is input, it will disable pull-up.
 * @param X Signal name.
 */
#define GPIO_OUTPUT_LOW(X)		(PORT(X) &= ~(1 << BIT(X)))
/**
 * @brief Reads a signal pin.
 * @param X Signal name.
 * @returns Signal logic level.
 */
#define GPIO_GET_INPUT(X)	    ((PIN(X) &   (1 << BIT(X))))

//////////////////////////////////////////////////
///////////       Signal names:       ////////////
//////////////////////////////////////////////////

// Defined here so that autocomplete will work for them.

#define UART_RX                 UART_RX
#define UART_TX                 UART_TX
#define ALE					    ALE
#define RD_N				    RD_N
#define WR_N				    WR_N
#define CLK					    CLK
#define RESET				    RESET
#define HOLD				    HOLD
#define HLDA				    HLDA
#define TEST_N				    TEST_N
#define READY				    READY
#define NMI					    NMI
#define INTR				    INTR
#define INTA_N				    INTA_N
#define SPI_MOSI			    SPI_MOSI
#define SPI_MISO			    SPI_MISO
#define SPI_SCK				    SPI_SCK
#define REG_OE_N			    REG_OE_N
#define RCLK_SH_LD_N            RCLK_SH_LD_N


//////////////////////////////////////////////////
///////       Signal to pin mapping:       ///////
//////////////////////////////////////////////////

// signals which use pin specific features (like pin interrupt, UART, SPI...):

// SPI:
#define SPI_MOSI_PORT		    B
#define SPI_MOSI_BIT		    3
#define SPI_MISO_PORT		    B
#define SPI_MISO_BIT		    4
#define SPI_SCK_PORT		    B
#define SPI_SCK_BIT			    5

// UART:
#define UART_RX_PORT		    D
#define UART_RX_BIT			    0
#define UART_TX_PORT		    D
#define UART_TX_BIT			    1

// Interrupt 0:
#define MCU_CS_PORT			    D
#define MCU_CS_BIT			    2

// Interrupt 1:
#define ALE_PORT			    D
#define ALE_BIT				    3

// Timer-0 OC0B:
#define CLK_PORT			    D
#define CLK_BIT				    5


// generic signals - can be remapped if neccessary:

#define BHE_IN_ADDRESS          (((uint32_t)1) << 20)
#define M_IO_IN_ADDRESS         (((uint32_t)1) << 22)

#define RCLK_SH_LD_N_PORT	    B
#define RCLK_SH_LD_N_BIT	    0
#define TEST_N_PORT			    B
#define TEST_N_BIT			    1
#define INTA_N_PORT			    B
#define INTA_N_BIT			    2

#define HOLD_PORT			    C
#define HOLD_BIT			    0
#define INTR_PORT			    C
#define INTR_BIT			    1
#define RD_N_PORT 			    C
#define RD_N_BIT			    2
#define NMI_PORT			    C
#define NMI_BIT				    3
#define HLDA_PORT			    C
#define HLDA_BIT			    4
#define WR_N_PORT			    C
#define WR_N_BIT			    5

#define RESET_PORT			    D
#define RESET_BIT			    4
#define REG_OE_N_PORT		    D
#define REG_OE_N_BIT		    6
#define READY_PORT			    D
#define READY_BIT			    7

#endif /* GPIO_H_ */

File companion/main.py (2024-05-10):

import logging
import argparse
import shlex
import sys
from companion import Companion

color_foreground = {'BLACK': '\x1B[30m', 'RED': '\x1B[31m', 'GREEN': '\x1B[32m', 'YELLOW': '\x1B[33m', 'BLUE': '\x1B[34m', 'MAGENTA': '\x1B[35m', 'CYAN': '\x1B[36m', 'WHITE': '\x1B[37m', 'RESET': '\x1B[39m'}

logger = logging.getLogger(__name__)
logging.basicConfig(filename='log.log', encoding='utf-8', level=logging.DEBUG)

companion = Companion()

# {command name: its description}, used as valid commands choices, as well as to generate an informative description.
commands: dict[str, str] = {
    "reset-coprocessor":    "reset coprocessor board",
    "read":                 "read from bus",
    "write":                "write to bus",
    "program":              "write to flash (programms flash)",
    "reset":                "resets 8086 and holds bus",
    "hold":                 "hold bus (stops 8086 code execution)",
    "release":              "release bus",
    "interrupt":            "generate interrupt",
    "reg_read":             "read a register",
    "reg_write":            "write to a register",
    "erase":                "erase flash",
    "help":                 "print help menu"
}

commands_interactive = {
    "quit":         "quit interactive session"
}

help_from_commands = lambda commands: "Available commands are:\n" + '\n'.join([f"\t {name:20} \t {desc}" for (name, desc) in commands.items()])



class ErrorCatchingArgumentParser(argparse.ArgumentParser):
    def exit(self, status=0, message=None):
        if status:
            raise argparse.ArgumentError(None, f'error: {message}')

parser: ErrorCatchingArgumentParser = None

def get_parser(interactive_or_cmd: bool) -> ErrorCatchingArgumentParser:
    description = ""
    epilog = "\n\n" + companion.about + "\nEldad Hellerman"
    if(interactive_or_cmd):
        description += help_from_commands(commands | commands_interactive)
        parser = ErrorCatchingArgumentParser(exit_on_error=False, formatter_class=argparse.RawDescriptionHelpFormatter, description=description, add_help=False, epilog=epilog)
    else:
        description += "To start an interactive Session, call the program without any arguments.\n\n" + help_from_commands(commands)
        parser = argparse.ArgumentParser(formatter_class=argparse.RawDescriptionHelpFormatter, description=description, add_help=False, epilog=epilog)
    
    type_autoint = lambda x: int(x,0)
    type_interrupt = lambda x: 256 if(x.upper()=="NMI") else int(x,0)
    type_uint32_t = lambda x: int(x,0).to_bytes(4, 'little')

    parser.add_argument("-s", "--start-address", metavar='start address', type=type_autoint, help="start address of read", dest="start-address")
    parser.add_argument("-e", "--end-address", metavar='end adresss', type=type_autoint, help="end address of read", dest="end-address")
    parser.add_argument("-l", "--length", metavar='length', type=type_autoint, help="length of data", dest="data-length")

    parser.add_argument("-o", metavar='output file', help="dump memory to file", dest="output-file")
    parser.add_argument("-i", metavar='input file', help="get input from file", dest="input-file")

    choices = list(commands) + (list(commands_interactive) if interactive_or_cmd else [])
    parser.add_argument("command", metavar='command', choices= choices, help="command to execute")

    parser.add_argument("-n", metavar='interrupt number', type=type_interrupt, help="interrupt number | 'nmi' (256 == 'nmi')", dest="interrupt-number")
    parser.add_argument("-r", metavar='register number', type=type_autoint, help="register name or number to use for read / write", dest="register-number")
    parser.add_argument("-d", metavar='register data', type=type_uint32_t, help="data to use for register write", dest="register-data")
    blocks_chip_erase = parser.add_mutually_exclusive_group()
    blocks_chip_erase.add_argument("-a", action="store_true", help="full chip erase", dest="chip-erase")
    blocks_chip_erase.add_argument("-b", metavar='flash block addresses', help="addresses of flash blocks to erase", nargs="+", dest="blocks")
    
    if(not interactive_or_cmd):
        parser.add_argument("-c", metavar='com port', help="Serial com port number", type=int, dest="com-port")
        parser.add_argument("--baud-rate", metavar='baud rate', help="Serial buad rate", type=int, dest="baud-rate", default=1000000)
    return parser

def get_start_address_and_length(start_address, end_address, data_length) -> tuple[int]:
    # exactly two of them must be specified:
    if(bool(start_address) + bool(end_address) + bool(data_length) != 2):
        return None
    if(not start_address):
        return (end_address - data_length, data_length)
    if(not end_address):
        return (start_address, data_length)
    if(not data_length):
        return (start_address, end_address - start_address)

def execute_read(start_address, end_address, data_length, output_file):
    start_address_and_data_length = get_start_address_and_length(start_address, end_address, data_length)
    if(not start_address_and_data_length):
        print("exactly two of the following must be specified: (start address, end address, data_length)")
        return
    start_address = start_address_and_data_length[0]
    data_length = start_address_and_data_length[1]

    if(output_file):
        try:
            with open(output_file, 'wb') as file:
                companion.read(start_address, data_length, file)
        except FileNotFoundError as e:
            print("output file is invalid.")
            print(e)
    else:
        companion.read(start_address, data_length, output_file=None)

def execute_write(start_address, end_address, data_length, input_file):
    valid = True
    start_address_and_data_length = get_start_address_and_length(start_address, end_address, data_length)
    if(not start_address_and_data_length):
        print("exactly two of the following must be specified: (start address, end address, data_length)")
        valid = False
    if(not input_file):
        print("input file must be specified")
        valid = False
    if(not valid):
        return
    start_address = start_address_and_data_length[0]
    data_length = start_address_and_data_length[1]
    
    try:
        with open(input_file, 'rb') as file:
            companion.write(start_address, data_length, file)
    except FileNotFoundError as e:
        print("input file is invalid.")
        print(e)
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

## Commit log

2023-08-29 first test of schmatic bus and PCB concept
    [8086 schematics and pcb.kicad_pcb, 8086 schematics and pcb.kicad_sch, module_8086.kicad_sch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]
2023-08-29 8086 module - bus connected
    [8086 schematics and pcb.kicad_sch, module_8086.kicad_sch, module_microcontroller.kicad_sch]
2023-08-30 8086 module - address latches, start of memory ICs
    [module_8086.kicad_sch]
2023-08-30 - changed SEG and IO pins to bidirectional - added "Local to Module" netclass.
    [8086 schematics and pcb.kicad_sch]
2023-09-10 split 8086 module to two files
    [module_8086.kicad_sch, module_8086_1.kicad_sch, module_8086_2.kicad_sch]
2023-09-10 basic start for microcontroller module
    [module_microcontroller.kicad_sch]
2023-09-10 basic start for IO module
    [8086 schematics and pcb.kicad_sch, module_io.kicad_sch]
2023-09-13 initial PCB layout with almost accurate footprints
    [8086 schematics and pcb.kicad_pcb, module_8086_1.kicad_sch, module_8086_2.kicad_sch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]
2023-09-13 move to single board design
2023-09-14 refactoring schematic files and structure
    [8086 board.kicad_pcb, 8086 board.kicad_sch, 8086 schematics and pcb.kicad_sch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]
2023-09-24 better schematic. initial pcb layout
    [8086 board.kicad_pcb, 8086 board.kicad_sch, io.kicad_sch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]
2023-09-27 adds assembler mnemonics
2023-10-01 adds local .gitignore file
    [8086 board.kicad_pcb]
2023-10-01 - all instructions encoded - improved instruction format encoding - improved instruction printing method
2023-10-15 - move preprocessor to assembler folder. - assembly syntax, directives, and preprocessor directives. - better makefile
2023-10-15 - move board readme to "8086 board" folder - create project readme file
2023-10-15 refactor "assembly syntax.md" to assembler README
2023-10-16 - add escaped char consts - printing from print.h (with colors)
2023-10-25 Schematic finished! (some footprint assignments are still needed)
    [8086 board.kicad_sch, io.kicad_sch, memory.kicad_sch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]
2023-10-26 -remove power switch -add testpoints for unused logic gate
    [8086 board.kicad_sch]
2023-10-26 -add LCD bus transceiver -add jumper for 7 segments common pin to ground or vcc
    [io.kicad_sch]
2023-10-26 change to 4 pin crystal
    [memory.kicad_sch, microcontroller.kicad_sch]
2023-10-27 change 7 segment to custom symbol and footprint
    [io.kicad_sch]
2023-10-27 initial pcb
    [8086 board.kicad_pcb]
2023-10-27 move assembling to assembler.c
2023-10-28 change to alternate pins of atmega328p
    [microcontroller.kicad_sch]
2023-10-28 change 74HC373D (SO20) to 74HC573PW (TSSOP20)
    [io.kicad_sch, memory.kicad_sch]
2023-10-29 change schematic to use new components
    [8086 board.kicad_sch, io.kicad_sch, memory.kicad_sch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]
2023-10-29 connect flash and ram together
    [8086 board.kicad_pcb, 8086 board.kicad_sch, io.kicad_sch]
2023-10-30 reduced schematic, PCB memory routed
    [8086 board.kicad_pcb, 8086 board.kicad_sch, io.kicad_sch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]
2023-11-01 schematic: reduced 8086 bus, no LCD shield
    [8086 board.kicad_sch, io.kicad_sch, memory.kicad_sch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]
2023-11-01 PCB: initial layout
    [8086 board.kicad_pcb]
2023-11-03 PCB: more layout work. some schematic changes.
    [8086 board.kicad_pcb, 8086 board.kicad_sch, io.kicad_sch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]
2023-11-08 PCB: different layout
    [8086 board.kicad_pcb, 8086 board.kicad_sch, io.kicad_sch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]
2023-11-10 PCB: layout and routing of IO, shift registers, and MCU
    [8086 board.kicad_pcb, 8086 board.kicad_sch, io.kicad_sch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]
2023-11-15 small schematic changes to better fit PCB
    [8086 board.kicad_sch, io.kicad_sch, memory.kicad_sch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]
2023-11-15 finish routing PCB
    [8086 board.kicad_pcb]
2023-11-15 remove LCD reset jumper
    [io.kicad_sch]
2023-11-15 finish main silkscreen
    [8086 board.kicad_pcb]
2023-11-19 schematic: fix LCD RD bug, geographical reannotation
    [8086 board.kicad_sch, io.kicad_sch, memory.kicad_sch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]
2023-11-19 PCB: done with silkscreen
2023-11-19 PCB: V1.0.1 - add JLC text - change plot settings to fit JLC - remove unnecessary ground plane traces
2023-11-29 fix labels
    [memory.kicad_sch, microcontroller.kicad_sch]
2024-01-07 add gpio pin mapping and utilities
2024-01-19 add uart
2024-04-26 - document uart - add uart_enable_rx_interrupt()
2024-04-26 add spi
2024-04-26 PCB: move to kicad 8
    [8086 board.kicad_sch, io.kicad_sch, memory.kicad_sch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]
